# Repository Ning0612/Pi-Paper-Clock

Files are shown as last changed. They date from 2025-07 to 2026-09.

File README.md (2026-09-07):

# Pico Paper Clock







基於 Raspberry Pi Pico W 與 Waveshare 2.9 吋觸控電子紙的 IoT 時鐘。它定位成放在書桌前、低干擾常駐的小顯示器：讓人抬頭即可看到日期、時間、目前天氣、室內溫濕度與喜歡的圖片，也能透過環境光感測器估算並追蹤在書桌前的時間。裝置同時透過 Wi-Fi 提供設定、圖片管理與在席統計頁面。

> **與 [epaper-home-display](https://github.com/Ning0612/epaper-home-display) 的關係**：兩者是各自獨立維護的不同作品。本專案定位為簡易的桌前小時鐘，跑在 Pico W／MicroPython 的 264KB RAM 資源受限環境；epaper-home-display 則是以 Raspberry Pi Zero 2W／Python 打造、整合多種資訊來源的智慧家庭顯示面板。

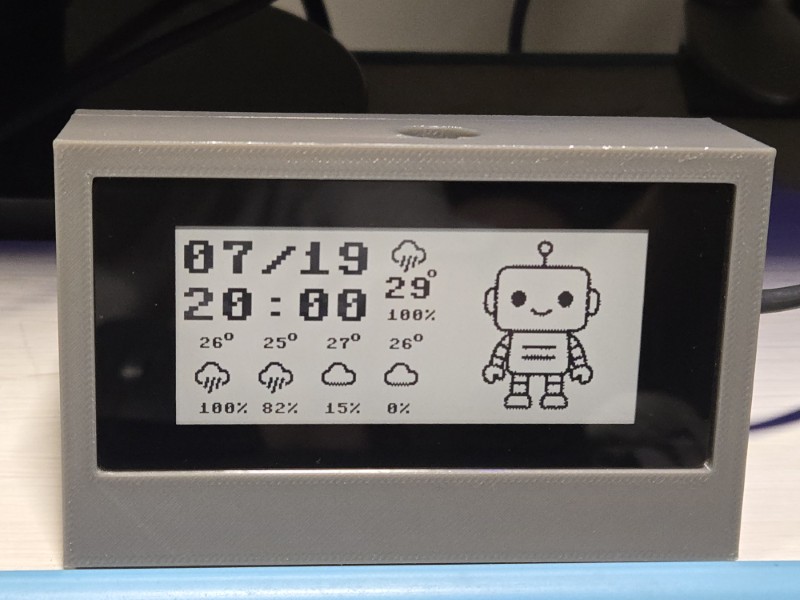
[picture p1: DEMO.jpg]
Project Demo


## Web UI 預覽

裝置在 AP 或 LAN 模式提供 Web UI，讓日常使用不必重新刷寫韌體即可管理顯示內容與查看書桌前活動：

- **裝置設定**：管理 Wi-Fi profile、天氣經緯度、圖片輪播、感測器與提示音，以及 AP 管理選項。
- **書桌前分析**：查看目前在席狀態、最近 24 小時與 30 天統計、年度熱力圖、每日紀錄和最近時段。
- **環境紀錄**：查看目前溫濕度、今日 min/max/avg，以及日/週/月/年趨勢圖與每日統計表。
- **圖片庫**：瀏覽 custom、events、login 圖片，預覽或刪除裝置上的素材；圖片上傳由 Pico Image Tool 處理。

<table>
  <tr>
    <td align="center">裝置設定頁<br><sub>裝置設定</sub></td>
    <td align="center">書桌前分析總覽<br><sub>書桌前分析：即時狀態與近期統計</sub></td>
  </tr>
  <tr>
    <td align="center">書桌前分析歷史資料<br><sub>書桌前分析：年度熱力圖與歷史紀錄</sub></td>
    <td align="center">圖片庫頁面<br><sub>圖片庫</sub></td>
  </tr>
</table>

## 功能概覽

- NTP 時間同步、目前天氣與未來預報。
- DHT22 溫濕度與環境光感測；低光時可讓電子紙進入休眠。
- 自訂圖片輪播、生日與 `MMDD` 事件圖片、觸控切換圖片。
- 多設定檔：依 Wi-Fi SSID 自動選擇家裡、公司等不同地點的設定。
- AP/LAN Web UI：管理設定檔、圖片、在席統計、環境紀錄與裝置狀態。
- 定時蜂鳴器提示，支援整點或每半小時響聲。

## 快速開始

### 1. 建立主機環境

Windows PowerShell：

```powershell
py -3 -m venv .venv
.\.venv\Scripts\python.exe -m pip install -r requirements.txt
```

完整部署流程、韌體安裝與疑難排解請參閱 [`docs/SETUP_GUIDE.md`](docs/SETUP_GUIDE.md)。

### 2. 準備設定並部署

1. 將 `src/config.json.example` 複製為未納入 Git 的 `src/config.json`，填入 Wi-Fi、各 profile 的天氣經緯度與其他設定；Open-Meteo 不需要 API Key。
2. 將 Pico W 以 USB 接上電腦，確認已安裝 MicroPython 與 `mpremote`。
3. 執行部署（將 `COM7` 換成實際序列埠）：

   ```powershell
   .\.venv\Scripts\python.exe tools\pico_deploy\upload_cli.py --port COM7 --no-config --no-clean
   ```

4. 啟動後若無法連上已知 Wi-Fi，裝置會建立 AP；連線至螢幕顯示的 SSID，再開啟 `http://192.168.4.1` 完成設定。

`tools\pico_deploy\upload_cli.py` 預設不會上傳或刪除裝置上的 `config.json`；只有明確指定 `--include-config` 才會納入本機設定。工具會在完成後重啟裝置並進入 REPL；按 `Ctrl+X` 離開。`--recursive-clean` 會刪除裝置上只存在於 runtime 的檔案與圖片，使用前請先備份。

`tools\pico_deploy\upload_cli.py` 是無 GUI 的 headless USB 部署入口；根目錄 `upload.py` 只保留作為相容 wrapper，一般 Windows 使用者可改用 Release 的 `PicoPaperClockTool` GUI。

## 硬體

必要元件為 Raspberry Pi Pico W、[Waveshare 2.9inch Touch e-Paper HAT](https://www.waveshare.net/wiki/Pico-CapTouch-ePaper-2.9)、LDR、DHT22、無源蜂鳴器與連接線。完整 pin map、接線圖與注意事項請見 [`docs/HARDWARE.md`](docs/HARDWARE.md)。

可選的 3D 外殼 CAD 檔案不放在 source tree；STEP 適合一般 CAD 編輯、STL 適合列印、SLDPRT 適合 SolidWorks 使用者，下載方式請見 [`docs/RELEASE_ASSETS.md`](docs/RELEASE_ASSETS.md)。

## 使用與設定

- 長按任一實體按鈕約 3 秒可要求裝置重啟並進入 AP 設定模式；不會刪除設定檔。
- AP 頁面可新增、編輯、刪除與切換設定檔；完整欄位、範圍、遷移與重置說明請見 [`docs/CONFIG_GUIDE.md`](docs/CONFIG_GUIDE.md)。
- 自訂圖片的資料夾、尺寸、事件命名與 GUI/CLI 用法請見 [`docs/IMAGE_GUIDE.md`](docs/IMAGE_GUIDE.md)。
- 圖片 HTTP API、認證要求與 `MONO_HLSB` 格式請見 [`docs/IMAGE_API.md`](docs/IMAGE_API.md)。
- Windows 使用者可下載 Release 的 `PicoPaperClockTool` EXE；序列部署時在 GUI 選擇含有 `src/` 的 repository/source zip，掃描序列埠後用選單選擇 Pico，部署前可在 Tree 檢視 manifest；LAN/AP 掃描結果也可選取，圖片批次上傳則可直接選取本機圖片。WebUI 帳號固定為 `admin`。

完全重置會刪除所有設定檔，必須在 AP 頁面的危險區域輸入 `RESET` 確認；這項操作無法復原。

## 開發與文件

```powershell
.\.venv\Scripts\python.exe tools\build_html.py
.\.venv\Scripts\python.exe -m unittest discover -s tests -v
```

GitHub Actions 會在 `main` push、pull request 與手動觸發時，以 Python 3.11/3.12 執行依賴安裝、HTML 生成物檢查、`compileall` 與 unittest。HTML 原始碼在 `tools/html_src/`，生成的 `src/html/*.bin` 不應手動編輯。專案資料流、記憶體限制與資料夾地圖請見 [`docs/ARCHITECTURE.md`](docs/ARCHITECTURE.md)，所有文件入口在 [`docs/README.md`](docs/README.md)。

桌面工具可由 source tree 建置：

```powershell
.\tools\build_pico_deploy_tool.ps1
```

輸出為 `dist\PicoPaperClockTool.exe`。建置與下載方式、序列部署安全選項及圖片批次流程請見 [`docs/IMAGE_GUIDE.md`](docs/IMAGE_GUIDE.md)。

## 授權與第三方資產

原創 source code 採用 [MIT License](LICENSE)。Waveshare 驅動與 weather-icons 圖示的授權邊界請見 [`THIRD_PARTY_NOTICES.md`](THIRD_PARTY_NOTICES.md) 與 [`ASSET_CREDITS.md`](ASSET_CREDITS.md)。

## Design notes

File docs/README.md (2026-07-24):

# Pico Paper Clock 文件索引

這個目錄收納需要長期維護的使用、設定、API 與架構文件；根目錄的 `README.md` 只保留專案介紹、快速開始與文件導覽，`AGENTS.md` 與 `CLAUDE.md` 保留給開發流程。

## 文件

- [架構與資料夾地圖](ARCHITECTURE.md) — 裝置資料流、記憶體邊界、圖片格式相容策略與維護規則。
- [硬體與接線](HARDWARE.md) — 元件、Pin map、感測器與蜂鳴器接線。
- [安裝、部署與 AP 設定](SETUP_GUIDE.md) — 主機環境、MicroPython、`tools/pico_deploy/upload_cli.py`、AP Web UI 與驗證。
- [設定指南](CONFIG_GUIDE.md) — schema v3、多設定檔、範圍與交易式保存。
- [圖片資產與轉換](IMAGE_GUIDE.md) — 資產目錄、尺寸、事件命名與 GUI/CLI。
- [圖片 API](IMAGE_API.md) — 裝置圖片列表、上傳、預覽、刪除與認證契約。
- [環境紀錄 API](ENV_LOG_API.md) — 溫濕度歷史記錄的取樣頻率、保留策略與 `/api/env/*` 契約。
- [Release assets](RELEASE_ASSETS.md) — GitHub Release 的 UF2、CAD 檔案與發布檢查表。

## 來源與生成物

- Web UI 原始碼位於 `tools/html_src/`。
- 執行 `tools/build_html.py` 生成 `src/html/*.bin`；不要直接編輯生成物。
- 圖片轉檔與 WebUI client 位於 `tools/pico_image_tool/`；Pico USB 部署核心與整合 GUI 位於 `tools/pico_deploy/`，入口為 `tools/pico_image_cli.py` 與 `tools/pico_image_gui.py`。

## 維護原則

1. API、設定欄位、硬體 pin 或資料夾變更時，更新對應詳細文件；根目錄 README 只維持摘要與入口連結。
2. 測試、PyInstaller 與 HTML 建置產物不放進 Git；`dist/` 僅作為本機交付物保留。
3. 既有使用者圖片、硬體 CAD 與網路上傳圖片不可因整理文件而刪除。

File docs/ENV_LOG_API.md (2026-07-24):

# Pico Paper Clock Environment Log API

環境（溫濕度）歷史記錄 API，架構與認證模型與 [`IMAGE_API.md`](IMAGE_API.md) 一致：只透過區域 HTTP 提供，皆為 **GET-only、唯讀**，只需 WebUI session cookie，不需要 CSRF token（因為不會異動任何狀態）。Server 不提供 CORS 或 TLS，只應暴露在可信任的 AP/LAN。

## 資料來源

DHT22 感測器每 `env_log.interval_min`（預設 15 分鐘，設定於 `global.env_log`，見 [`CONFIG_GUIDE.md`](CONFIG_GUIDE.md)）取樣一次，寫入 `env_events.log`（原始樣本）；每日 00:00 換日時彙總成一筆 `env_daily.log`（每日 min/max/avg），同時裁切掉 7 天前的原始樣本與 366 天前的每日彙總。裁切只在換日當下執行，不是即時保證——裝置斷電/關機一段時間後重開機，`env_events.log` 中舊資料要等到下一次換日才會被裁掉，這段期間查詢可能看到超過 7 天的資料。取樣獨立於在席狀態與畫面更新，離開書桌、螢幕休眠時仍會持續記錄。

## Collections

| Path | 方法 | 說明 |
|---|---|---|
| `/environment` | GET | 環境紀錄 WebUI 頁面（gzip 過的靜態頁面） |
| `/api/env/status` | GET | 目前溫濕度與今日 min/max/avg 統計 |
| `/api/env/samples` | GET | 原始樣本串流（保留視窗 7 天，於每日換日時裁切，非即時保證，見下方「資料來源」） |
| `/api/env/daily` | GET | 每日彙總串流（保留視窗 366 天，同上） |

## `/api/env/status`

```json
{
  "temp": 24.5, "hum": 55.2,
  "current_date": "20260721",
  "t_min": 22.1, "t_max": 26.8, "t_avg": 24.3,
  "h_min": 48.0, "h_max": 60.5, "h_avg": 54.1,
  "count": 18,
  "now_epoch": 1784712000
}
```

裝置尚未完成第一次取樣時，`temp`/`hum`/`t_min`/`t_max`/`t_avg`/`h_min`/`h_max`/`h_avg` 為 `null`、`count` 為 `0`。

## `/api/env/samples`、`/api/env/daily`

與 presence 的 `/api/desk/timeline`、`/api/desk/daily` 相同，使用 bounded streaming（逐行讀取＋512 bytes chunk 傳送），不會把整份 log 讀進記憶體。

`/api/env/samples` 回傳陣列，每筆為單一原始樣本：
```json
{"d":"20260721","tm":"1415","t":25.4,"h":58.0,"e":1784721300}
```

`/api/env/daily` 回傳陣列，每筆為單日彙總：
```json
{"d":"20260721","tmin":22.1,"tmax":29.8,"tavg":25.6,"hmin":45.0,"hmax":61.0,"havg":53.2,"n":96}
```

損壞或欄位不足的 log 行會被跳過，不會中斷串流。

## 錯誤與認證

未登入存取任何 `/api/env/*` 端點回傳 `401 {"error":"auth_required"}`；存取 `/environment` 頁面則導向 `/login`。裝置管理員密碼尚未設定時，所有端點皆視為需要先完成首次設定。

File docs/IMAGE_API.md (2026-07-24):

# Pico Paper Clock Image API v1

API 只透過區域 HTTP 提供。`GET /api/v1/device` 允許未驗證探索；裝置完成首次設定後，所有圖片清單與異動都需要 WebUI session cookie。`PUT`、`POST`、`DELETE` 另需 `X-Pico-Clock-API: 1` 與 session CSRF token。Server 不提供 CORS 或 TLS，只應暴露在可信任的 AP/LAN。

首次設定時，瀏覽器先以 `GET /api/v1/auth/status` 取得 per-boot CSRF token，再以 `POST /api/v1/auth/login` 設定固定帳號 `admin` 的管理密碼或登入。成功後回傳 `HttpOnly; SameSite=Strict` 的 `session` cookie 與 session CSRF token。裝置只保留一組 server-side session slot；新登入會使舊 session 失效，閒置 30 分鐘或絕對時間 24 小時後過期，重開機、登出或變更密碼也會失效。

## 探索

`GET /api/v1/device` 回傳固定的 `device: "pico-paper-clock"`、整數 `api_version: 1`、可用 heap/storage 與圖片尺寸。Client 必須拒絕未知 device 或 API 版本。

> v2.6.0 起裝置回傳的識別字串由 `pi-paper-clock` 改為 `pico-paper-clock`。桌面工具同時接受兩者，因此尚未更新韌體的裝置仍可正常連線。

## Collections

| Collection | Resource | 大小 |
|---|---|---:|
| custom | `/api/v1/images/custom/{name}.bin` | 解壓後 2,048 bytes |
| login | `/api/v1/images/login/{name}.bin` | 解壓後 4,736 bytes |
| events | `/api/v1/images/events/{MMDD|birthday}/{name}.bin` | 解壓後 2,048 bytes |

名稱由 1–48 個 ASCII 字母、數字、`_`、`-` 加上 `.bin` 組成。新工具上傳的 payload 一律是帶 PPC1 header 的 bitmap；PPC1 header 保存 bit order，裝置以 bounded streaming decoder 還原。API 仍接受既有固定長度 raw `MONO_HLSB`，並以 `.bin.hlsb` marker 維持舊資產相容性；無 marker 的既有 raw 圖片仍按舊版 MSB-left 讀取。

## 圖片操作

- `GET /api/v1/images?collection=custom|login|events&event=MMDD|birthday` 串流回傳 JSON `items`、`fs_free`、`catalog_generation`。
- `PUT <resource>?overwrite=0|1&preview=0|1` 需要 `application/octet-stream` 與精確 `Content-Length`。裝置會先串流寫入並驗證 raw／PPC1 解碼後長度，再以 `.part`、`.bak` 替換；開機會復原中斷交易。
- `DELETE <resource>` 刪除一張圖片並立即使 catalog 失效。
- `POST <resource>/preview` 排入一次電子紙預覽，不改變輪播順序。

上傳成功回應中的 `bytes` 是裝置實際儲存大小；`uncompressed_bytes` 是解壓後大小；`compressed` 表示是否使用 PPC1。

錯誤 body 為包含 `error` 與 `message` 的短 JSON；常見 status 為 `400`、`401`、`404`、`409`、`411`、`413`、`500`、`507`。

## 設定 Web API

- `GET /api/v1/config[?profile=name]` 回傳已遮蔽的 profile、profile 名稱、active profile、CSRF token 與「secret 已設定」布林值，永不回傳儲存的密碼、API key 或 webhook。
- `GET /api/v1/networks` 執行即時 Wi-Fi 掃描並回傳可見網路；掃描失敗回 `500`，不會修改既有設定。
- `POST /api/v1/config` 接受最多 4 KiB `application/x-www-form-urlencoded`，需要 CSRF token，驗證數字範圍，單次交易保存後排程重啟。空白 secret 欄位會保留原值。

所有受保護的 LAN/AP 設定 API 都需要 session cookie。設定異動、圖片異動與危險操作只接受 POST/PUT/DELETE，並驗證 `X-CSRF-Token`；圖片異動仍必須帶 `X-Pico-Clock-API: 1`。HTTP 沒有傳輸加密，session token 與 CSRF token 可能被同網段攻擊者攔截重放，請限制在可信任的隔離網路。

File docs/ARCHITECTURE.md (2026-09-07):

# 架構與資料夾地圖

## 裝置資料流

```text
main.py
  └─ AppController
       ├─ HardwareManager / PresenceManager
       ├─ ConfigManager（config.json，交易式 tmp/bak）
       ├─ ImageStore + ImageCatalog（串流列舉、輪播、預覽佇列）
       ├─ DisplayManager → RotatedCanvas90 → EPD_2in9
       └─ LanConfigServer / AP web server → wifi_manager dispatcher
```

啟動時先連線、同步 NTP 時間並嘗試發送 Discord LAN IP 通知；在載入控制器、顯示與感測器工作路徑前，會利用低記憶體窗口 flush pending Discord queue，再復原圖片交易檔並建立 LAN server。LAN 與 AP 共用路由；AP 額外保留按鈕長按、閒置 timeout、profile fallback 與 reboot 工作。

`main.py` 會在建立 controller 之前無條件畫出開機畫面，因此主迴圈接手時面板一定是醒著且有內容的。離席時的顯示收斂據此設計為**狀態驅動**：`state.display_asleep` 初值為 `False`，主迴圈只要看到 presence 不在席且旗標未設，就清屏、送入睡眠並設起旗標。之所以不能只監聽在席→離席的轉換，是因為在暗處開機時根本不存在該轉換（第一輪就已是離席），開機畫面會因此永遠留在面板上、電子紙也不會睡眠——而 Discord 記憶體保底重啟正好讓「暗處開機」成為常態路徑（見下方記憶體邊界）。圖片預覽也一併改為在迴圈開頭消耗、在在席分支繪製，**只取代該輪的頁面渲染而不短路整輪迴圈**；離席時預覽丟棄不繪製，面板維持睡眠。原本在迴圈開頭 `return` 的寫法讓客戶端只要每輪送一次 `preview=true`，就能使 `presence.update()`（連帶離席 debounce）、環境取樣、按鈕處理與 `_check_discord_stall()` 永遠不執行。

## 記憶體邊界

- 顯示使用一份 native `128 × 296` framebuffer，透過 rotated canvas 提供原本的 `296 × 128` 邏輯座標。
- 顯示更新會重用 native framebuffer、rotated canvas、字型 glyph buffer 與常用圖片列 buffer；避免每次刷新重新配置約 4.7 KB framebuffer 與重複的小型暫存物件。進入一般 Discord 網路傳送前會釋放大型 display workspace，保留 TLS 所需的連續 heap 空間。
- 圖片以固定列 buffer 讀取；網路上傳以 512-byte buffer 串流，不把整張圖片載入 RAM。
- SPI 傳送使用 buffer write，避免逐 byte 建立暫時物件。
- 長生命週期 controller、presence、image store/catalog 使用 `__slots__`。
- Discord webhook 不使用 `urequests.Response` 路徑，改用 raw `ssl` socket：只建立固定大小的 HTTP headers/payload、處理 partial write、讀取 status line 後立即關閉 socket；送出前後執行 `gc.collect()`，並暫時調整 GC threshold 後恢復原值。NTP 會在第一次 TLS 呼叫前同步；目前 firmware tree 尚未附帶 CA trust anchor，因此此連線仍不能宣稱完成憑證鏈／hostname 驗證，正式部署前需補上 CA bundle，不能以不驗證的 TLS 取代。
- Discord JSON payload 以單一 `bytearray` 組裝，避免字串串接時留下額外完整 payload copy；Discord socket 在建立與 TLS 前會記錄 heap free/allocated telemetry。
- 啟動通知與 pending Discord queue 在 `main.py` 的低依賴啟動階段先執行，避開 controller/weather 後續模組 import 與 display/hardware 工作物件建立造成的 heap 碎片；第一次失敗不阻塞主程式，controller 會在 45 秒後、每 30 秒重試，pending queue 則保留到下一次可用窗口（`presence_pending.log`／`presence_session_pending.log` 另有 7 天保留上限，超過天數的通知會被裁切捨棄，不會無限期等待重試，見下方「Flash 儲存邊界」）。
- **記憶體自動重啟後，IP 未變就不再送「已上線」通知**。那次重啟買到的是唯一一個可用的 TLS 窗口，而啟動階段原本第一件事就是重發一則使用者早已知道的 IP 通知，把窗口用掉、pending 在席通知只能再等下一次重啟（至少 2 小時）。`_check_discord_stall()` 因此在 `machine.reset()` 前把當下**已公告過**的 IP 寫入 `discord_autoreset_ip.log`，`main.py` 在啟動窗口讀取後立即刪除：IP 相同就跳過通知並標記為已送（避免 controller 每 30 秒重試），窗口留給 `flush_startup_discord()`。只記錄確實送出過的 IP——從未公告成功的位址仍要照常嘗試，否則使用者無從得知裝置在哪。記錄採**讀取即消費**，所以手動斷電重開、或 IP 真的變了，都會照常送出；消費在「是否連上網路」的判斷之外執行，否則一次沒連上線的開機會把記錄留給後面某次本該公告的開機。刪除失敗時視為「沒有消費到任何東西」並照常公告——殘留的記錄否則會在每一次相同 IP 的開機持續抑制通知，多送一則遠優於從此靜默。「IP 沒變」的定義就是 IPv4 字串相同：換到另一個網路卻拿到相同位址時同樣會被抑制，但公告過的 URL 在該網路上仍然可用，且記錄只存活於「自動重啟 → 它造成的那次開機」之間，搬移裝置必然經過斷電而清掉記錄。
- Discord `ENOMEM` 會回傳可重試結果；presence queue 在記憶體壓力後暫停一個 flush interval，之後自動恢復嘗試，不丟棄 pending session/summary。
- **TLS 需要的是連續區塊，不是可用總量**。`ssl.wrap_socket` 的成敗門檻量測（MicroPython 1.24.1，2026-07-25，純 `.py` 部署）：最大連續區塊 17,920 B 時直接 `OSError [Errno 12] ENOMEM`，23,120 B 時成功。`TLS_MIN_CONTIGUOUS_BYTES` = 20 KiB 即取自這段區間。實測清除天氣快取與重複 `gc.collect()` 對最大連續區塊完全無效。
- **目前的 heap 基線見下方 2026-07-26 複測，不是上一行的 17.9 KB**。上一行只用於界定 TLS 的成敗門檻；當時記錄的「運行中最大連續區塊約 17.9 KB」已被後續量測取代，勿再引為現況基線。
- **`release_display_workspace()` 增加的是 `mem_free`，不是最大連續區塊**。2026-07-26 於 `.mpy` 部署、開機約 3 分鐘的實機複測：呼叫後 `mem_free` 由 56,512 B 升至 61,584 B（+5,072 B），但最大連續區塊在呼叫前後**同為 10,240 B，完全沒有移動**——釋放出的空間不在關鍵位置。同次量測的穩態為 `mem_free` 56,512 B／`mem_alloc` 133,440 B，最大連續區塊約 10 KiB，**只有 20 KiB 門檻的一半**；裝置端 `discord_diag.log` 同期記錄的 `largest=10240`／`13312` 與此一致。因此在這個部署下，穩態送不出去是常態而非暫時性壓力，而**目前唯一觀察到能成功送出的時機**是重開機後、模組尚未載入的低記憶體啟動窗口（`main.py` 的 `flush_startup_discord()`）。此結論的證據是單一裝置、單一韌體與 `.mpy` 部署下的量測，其他部署模式（純 `.py`、不同韌體、模組數量變動）需重新量測才能沿用。不要再把 `release_display_workspace()` 當成能救回這條路徑的手段。
- `flush_discord()` 因此在釋放 display workspace 之後、送信之前執行 pre-flight 檢查（`has_tls_headroom()`，門檻 `TLS_MIN_CONTIGUOUS_BYTES` = 20 KiB）。不足時跳過本次嘗試並累計失敗計數，避免把約 3 秒耗在必定失敗的 handshake 上。失敗原因與當下最大連續區塊寫入 `discord_diag.log`（第 1 次與其後每 10 次），失敗診斷因此能在斷電後保留。
- **記憶體探針之前必須先問「這則訊息本來就送得出去嗎」**：`delivery_blocked()` 會先判斷 webhook 是否設定、STA 是否連線，回傳 `nowebhook`／`offline`／`""`。順序反過來的話，「沒設定 webhook」或「斷網」會被記成記憶體不足，累積後觸發一個根本幫不上忙的重開機。三個 `send_*` 函式共用同一份判斷，避免兩處條件漂移。
- 碎片化一旦讓連續區塊長期不足，**只有重開機能取回連續 heap**。`app_controller` 在**記憶體類失敗**（`lowmem`／`enomem`，由 `presence.discord_mem_failures` 單獨計數）達門檻、仍有 pending、且開機滿 `DISCORD_STALL_MIN_UPTIME_MS`（5 分鐘）時執行 `machine.reset()`。HTTP 錯誤或斷網會把該計數歸零，**因此這類失敗本身不會觸發任何重啟**——這正是歸零的目的：重開機修不好一個被刪除的 webhook，少了這道區分才會退化成每 2 小時重啟一次。
- **門檻依在席狀態而定，因為它衡量的是重開機當下的代價，不是堵塞已持續多久**（`_stall_reset_threshold()`）。離席時 `DISCORD_STALL_AWAY_FAILURES`（2 次，約 2 分鐘）：`presence_manager` 只在「離開書桌」的 transition 產生 pending session summary，所以幾乎所有待送通知誕生時面板都已清屏睡眠、使用者不在場，重開幾乎沒有可感知的代價。在席或狀態未知（`current_state` 為 `None`，第一次 presence 判定之前）時 `DISCORD_STALL_PRESENT_FAILURES`（10 次，約 10 分鐘），因為重開會讓使用者盯著開機畫面等 Wi-Fi 重連與 NTP。**在席門檻不可改成「永不」**：光感若把亮著的空房間讀成在席，only-away 觸發就永遠不會發生，通知會卡得比引入這個機制之前更久。
- 觸發判斷採 `stall_checked_failures`／`stall_checked_threshold` latch，不是「失敗數為門檻的整數倍」。同一組（失敗數，門檻）只評估一次，因此冷卻檔仍維持每次失敗才讀一次（約 60 秒），不會每輪主迴圈都讀 flash；而失敗數或門檻任一改變就重新評估，所以使用者離開書桌使門檻下降時會立即重評，被 uptime gate 或冷卻擋掉的檢查也只延後到下一次失敗（約 60 秒），不像倍數寫法會直接延到第 2N 次而使延遲加倍。這也解除了 gate 與門檻的耦合：`DISCORD_STALL_MIN_UPTIME_MS` 只需長於啟動通知窗口（`STARTUP_DISCORD_DELAY_MS` 加一次 `STARTUP_DISCORD_RETRY_MS`），由 `test_uptime_gate_outlasts_the_startup_window` 把關。失敗數在送出成功後歸零時 latch 一併重設，避免計數重新爬回同一個值時漏掉一次評估。
- 門檻降低**不保證**「每批 backlog 只花一次重啟」：pending 是以 `_append_line` 累積、`_drop_first_line` 消耗的佇列，而 `flush_startup_discord()` 每次開機最多清 8 筆，冷卻是 per-reboot 而非 per-backlog。目前每天約 2–6 筆的量遠低於此上限，但 backlog 一旦深於 8 筆，清空就需要跨多次重開機。
- 自動重啟的保險：pending 未能寫入 flash（`pending_persist_failed`）時放棄重啟，否則會遺失只存在於 RAM 的通知；冷卻時間戳寫入失敗時放棄重啟並封鎖本次開機（fail-safe，不重啟優於 boot loop）；`discord_autoreset.log` 於執行期即時評估，冷卻可在運行中自然到期。**冷卻檔只有「檔案不存在」是 fail-open，其餘一律 fail-closed**：不存在代表從未自動重啟過，第一次不可被擋；其他讀取錯誤（`OSError` 非 ENOENT）與時鐘不可用則直接拒絕，因為此時冷卻狀態是「未知」，而未知不能讀成「允許」——間歇性的 flash 讀取失敗否則每失敗一次就放行一次重啟。檔案存在但內容不可用（截斷寫入、區塊損毀、`<= 0` 的數值）則重寫一個新的時間戳並拒絕本次重啟；若連重寫都失敗就設起 `auto_reset_blocked`，與呼叫端寫入失敗時的處置一致。**時間戳比當下時鐘還新時同樣走重寫路徑**：Pico W 沒有電池供電的 RTC，NTP 同步失敗的那次開機會讓 `time.time()` 從 port epoch 重新起算，於是由已同步開機寫下的時間戳永遠落在未來、差值恆為負；把它讀成「冷卻未到期」會讓保底重啟一路被封鎖到 NTP 再次成功，讀成「已到期」則會每輪都放行、而每次重啟又重置時基。重寫成當下時基並等滿一次冷卻是唯一不會卡死也不會失控的處置。把損毀讀成「從未重啟過」等於放棄唯一的 boot-loop 防護，而在離席門檻（約 2 分鐘）下那會退化成每次 uptime gate 到期就重開一次。
- **離席分支的清屏睡眠必須包在 try/except 內**：`main.py` 以 `while True: controller.run_main_loop()` 裸迴圈驅動、未包例外處理，而 `clear_display_and_sleep()` 位於 `_check_discord_stall()` 之前，因此它拋出的例外會終止整個主程式，並讓最需要保底重啟的時刻永遠等不到重啟。失敗時不設起 `display_asleep`，但改以 `DISPLAY_SLEEP_RETRY_MS`（60 秒）退避後再試——完整清屏加面板初始化的成本太高，每秒重試一次會排擠 LAN polling、presence 更新與 stall 檢查並灌爆 UART log。「開機滿 5 分鐘」以 latch 記錄而非每次重算——`ticks_ms()` 為 30-bit、`ticks_diff()` 僅在約 ±6.2 天內有效，而這個故障正好出現在約 12 天的連續運行之後。
- DHT22 使用 2500 ms 最小讀取間隔；讀取失敗改用 10 秒 backoff，保留上一筆快取值，避免感測器錯誤反覆消耗 heap 與刷 serial log。
- 天氣資料改由 Open-Meteo 提供：current request 取得目前溫度與 WMO condition code，daily request 取得 5 天平均/高低溫、降雨機率與降水量；以 `response.json()` 解析小型 5-day payload，完成後立即釋放 response 與資料物件並回收 heap。既有 display icon 名稱由 WMO code mapping 保持不變。
- 天氣 request 前、response 取得後與 forecast parse 後會記錄 heap telemetry；API 的 `timezone` 由 profile 的固定 `timezone_offset` 轉成 IANA `Etc/GMT` zone，使預報日期與裝置日期一致。Presence API 的記憶體讀取介面只保留最近 128 筆事件與 366 筆 daily lines，且單行最多讀取 256 字元；完整串流 API 仍逐行送出。
- `/api/v1/device` 的 `heap_free` 可作為現場基線；完整 peak／長跑數據仍需接上指定 Pico 後量測。

### 記憶體問題的處理原則

```text
啟動 Wi-Fi
  └─ raw HTTPS Discord webhook
       ├─ 成功：記錄已送出，釋放 socket
       └─ ENOMEM：保留可重試狀態，不阻塞主迴圈
            ↓
載入 display / HardwareManager / AppController
  └─ 天氣 forecast 以 5-day JSON payload 解析並立即釋放
  └─ DHT22 依時間節流，失敗使用 backoff 與快取
```

這些策略的目標是降低「單次配置峰值」與重複配置頻率，而不是宣稱裝置 heap 永遠不會耗盡。現場診斷應同時查看 serial 的 `ENOMEM`、`Memory before/after ...` telemetry、DHT22 錯誤與 `/api/v1/device` 的 `heap_free`。**Discord 送不出去時優先查裝置上的 `discord_diag.log`**：`lowmem` 事件附帶當下的最大連續區塊，可直接判斷是碎片化還是 webhook 本身的問題（後者記錄為 `http<狀態碼>`）。注意 `heap_free` 充足並不代表 TLS 可用——關鍵指標是最大連續區塊。

## Flash 儲存邊界

`presence_manager.py` 與 `env_manager.py` 的 log 檔案都存在裝置的內部 flash 檔案系統上，與韌體、`config.json`、`src/image/` 圖片資產共用同一個有限空間（在一台已使用一段時間、圖片庫已有內容的裝置上，剩餘可用空間可能只有約 100 KiB 等級）：

- 兩個模組都採「事件/樣本檔＋每日彙總檔」的雙檔設計，並在每日換日時以 `_trim_by_date` 依日期視窗裁切——檔案大小會在保留視窗內收斂到穩定值，不會隨時間無限增長。
- `env_events.log`（15 分鐘取樣、7 天保留）穩態約 17 KiB；`env_daily.log`（每日彙總、366 天保留）穩態約 15 KiB；新增的 `environment.bin` WebUI 資產約 6.7 KiB（實測，`tools/build_html.py` 輸出）。三者合計約 40 KiB 是這次新增功能的穩態 flash 佔用。
- 裁切/換日時的 `.tmp`/`.bak` 交易寫入（`_commit_tmp`）會暫時需要被重寫檔案的一整份額外空間；`env_events.log` 裁切瞬間約需額外 17 KiB。
- `discord_diag.log` 上限 6 KiB，超過時串流捨棄較舊的一半（同樣使用 `.tmp` 交易寫入，瞬間額外需求不超過檔案本身）；`discord_autoreset.log` 只存一個 epoch 時間戳，`discord_autoreset_ip.log` 只存一個 IP 字串且讀取後即刪除，量級皆可忽略。
- **實測建議**：完成部署後應以裝置 REPL 執行 `os.statvfs('/')` 或呼叫 `GET /api/v1/device` 的 `fs_free` 欄位覆核實際剩餘空間，不要只依賴這裡的估算值。7 天保留的原始/事件 log（`env_events.log`、`presence_events.log`）約一個月內就會穩定在保留視窗內的穩態大小；366 天保留的每日彙總 log（`env_daily.log`、`presence_daily.log`）要接近一整年才會長到穩態上限，短期量測看到的每日彙總檔案會比長期穩態小很多，不能用一個月的量測值直接外推。若空間明顯吃緊，`env_manager.DAILY_RETENTION_DAYS`（預設 366，比照 `presence_manager.DAILY_RETENTION_DAYS`）可調降以換取空間。
- **`.py` 原始碼是目前最大宗的 flash 佔用來源**：一台已部署 presence／env 功能且圖片庫有內容的裝置，18 個 `.py` 檔案合計約 226 KB，佔裝置總佔用（307 KB）的 74%，遠超過圖片資產（~50KB）與 Web UI `.bin` 資產（~38KB）。`tools/pico_deploy/upload_cli.py --mpy` 可在部署前用 `mpy-cross` 把 `.py` 預編譯成 `.mpy` bytecode（`epaper.py`／`main.py`／`config.json` 除外，理由見 `CLAUDE.md`「部署至裝置」一節），是目前最有效的省空間手段。**實測**（2026-07-22，裝置 MicroPython 1.24.1）：18 個原始碼檔案從約 226 KB 壓到約 101 KB，裝置剩餘 flash 從 88.0 KiB 提升到 204.0 KiB（多出 116 KiB），比社群估計的 30–50% bytecode 縮減比例更好。**裝置剩餘空間吃緊時建議部署加上 `--mpy`**；這仍是 opt-in 選項而非預設行為——目前沒有部署前韌體版本檢查機制，`mpy-cross` 版號與裝置實際韌體版本漂移會讓 `.mpy` 模組 import 失敗，加上回滾（切回純 `.py`）流程尚未完整驗證，暫不建議設為預設。

## 圖片格式與相容性

- raw 圖片 payload 的 canonical 格式是 `MONO_HLSB`，每個 byte 的 bit 0 是最左像素；新工具一律寫入帶 HLSB header 的 PPC1 `.bin`。
- PPC1 header 保存 bit order，裝置透過 256-byte history、512-byte input buffer 與既有 row buffer 逐列解壓，不把整張圖片載入 RAM。
- 新工具與 USB manifest 不建立或部署 `.hlsb` sidecar；PPC1 自帶 bit order metadata。
- 韌體仍接受 raw API／既有 raw 資產的 `.hlsb` marker，以維持升級相容性。
- 沒有 marker 的既有 repository／舊版 runtime raw `.bin` 仍按 MSB-left 解碼，避免升級時破壞既有圖片。
- `custom`／`events` 為 `128 × 128`、2048 bytes；`login` 為 `296 × 128`、4736 bytes。

## HTTP 邊界

- `/api/v1/device` 可匿名讀取；圖片與設定 API 在完成首次設定後需要 WebUI server-side 單一 session、CSRF token，圖片變更另需 `X-Pico-Clock-API: 1`。
- 設定頁、圖片頁、儀表板與感測資料在 LAN/AP 共用同一 session dispatcher；首次出廠 AP 允許完成首次密碼設定，之後即要求 session。
- session 使用 128-bit CSPRNG token、idle 30 分鐘／absolute 24 小時 monotonic timeout；重開機、登出與密碼變更會撤銷 session。管理密碼以 PBKDF2-HMAC-SHA256 儲存。
- 管理介面仍是 HTTP；請限制在可信任的隔離 LAN/AP，因 HTTP 無法防止 session token 被同網段攔截重放。
- body 只接受單一 `Content-Length`，拒絕重複長度與 `Transfer-Encoding`。
- request 有總讀取 deadline；Pico W 正常圖片串流使用 8 秒上限。
- 圖片寫入採 `.part`、`.bak` 與 marker transaction，開機會復原未完成狀態。

## 資料夾地圖

| 路徑 | 用途 | 維護規則 |
|---|---|---|
| `src/` | MicroPython firmware | 不使用 CPython-only API |
| `src/image/` | 裝置圖片資產 | 保留既有圖片；API runtime 圖片由裝置管理 |
| `src/html/` | 生成後的 Web UI `.bin` | 由 `tools/html_src/` 建置 |
| `tools/html_src/` | 可讀 HTML/CSS/JS 來源 | UI 修改只改這裡 |
| `tools/pico_image_tool/` | 圖片轉檔、抖動、codec、WebUI client、圖片 CLI | 主機端 Python |
| `tools/pico_deploy/` | Pico USB/`mpremote` 部署核心、manifest、作業佇列與整合 GUI | 主機端 Python |
| `tests/` | 主機回歸與協議測試 | 使用專案 `.venv` |
| `docs/` | 長期文件與契約 | API／設定／架構同步更新 |
| `dist/release-assets/` | 本地發布暫存的 UF2、STEP、STL 與 `.SLDPRT` | 已被 Git 忽略；建立 Release 時手動附加；不放回 source tree |

## 部署與驗證

```powershell
.\.venv\Scripts\python.exe tools\build_html.py
.\.venv\Scripts\python.exe -m unittest discover -s tests -v
.\.venv\Scripts\python.exe tools\pico_deploy\upload_cli.py --port COM6 --no-clean
```

本次記憶體路徑的最低驗證包括 host tests、`compileall`、`git diff --check`，以及 Pico W serial 中的 `Success: Discord LAN IP notification sent.`、DHT22 讀值與天氣請求成功。完整 peak heap 仍應以實際硬體長跑資料為準。

Pico 部署工具 EXE 由 `tools/build_pico_deploy_tool.ps1` 建置。若使用遞迴清理，部署前要先保存裝置上只有 runtime 的圖片。

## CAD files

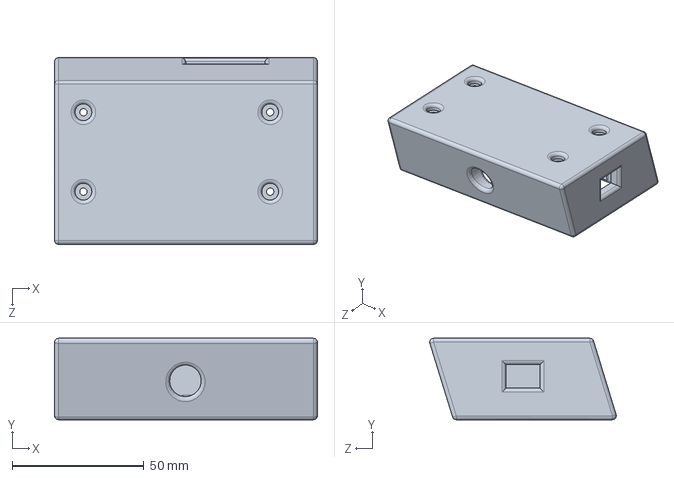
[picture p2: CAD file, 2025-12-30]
hardware/clock_v3.SLDPRT
100.0 x 31.0 x 71.0 mm

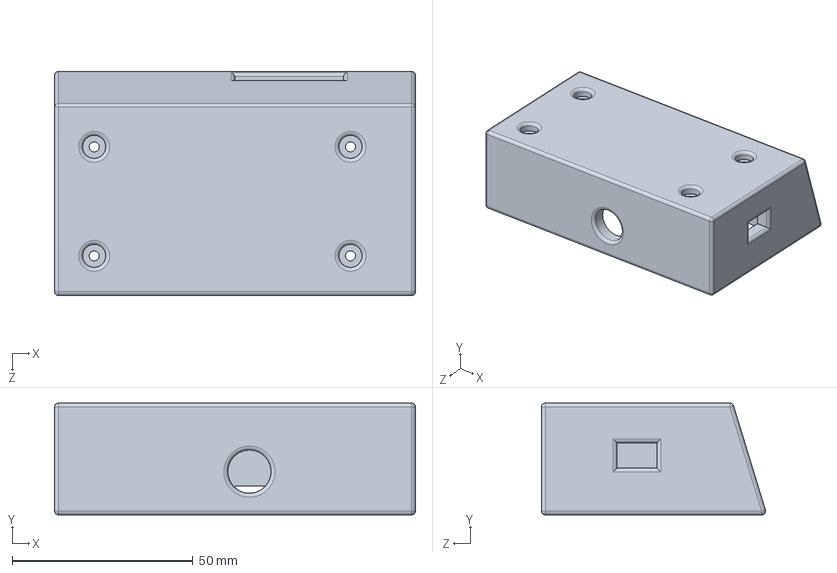
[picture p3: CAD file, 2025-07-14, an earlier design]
hardware/clock.SLDPRT
100.0 x 31.0 x 62.1 mm

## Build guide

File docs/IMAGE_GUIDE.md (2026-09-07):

# 圖片資產與轉換

本文件說明 repository 內的圖片資產、整合式桌面上傳工具與批次流程；HTTP 上傳、認證、交易寫入與位元排列請以 [`IMAGE_API.md`](IMAGE_API.md) 為準。

## 資產目錄

所有裝置圖片位於 `src/image/`，以 1-bit bitmap 儲存。新工具一律輸出帶 PPC1 header 的 `.bin`；即使壓縮後稍大，也不會產生 `.bin.hlsb` sidecar：

| 路徑 | 用途 | 尺寸 |
|---|---|---:|
| `custom/` | 一般輪播圖片 | 128 × 128 |
| `events/birthday/` | 生日圖片 | 128 × 128 |
| `events/MMDD/` | 特定日期圖片，例如 `events/1225/` | 128 × 128 |
| `login/` | 啟動與連線過渡畫面 | 296 × 128 |
| `weather_icons/` | 天氣狀態圖示（依 WMO code 對應） | 32 × 32 |

事件資料夾使用四位數 `MMDD`；檔名使用 `.bin`。Weather icons 是系統資產，不透過圖片 API 修改。

## 整合 GUI 與 CLI

GUI 入口：

```powershell
.\.venv\Scripts\python.exe tools\pico_image_cli.py gui
```

GUI 由 `tools/pico_deploy/` 提供，分成序列部署、圖片批次與作業佇列；圖片轉檔與 WebUI client 仍由 `tools/pico_image_tool/` 提供。序列部署前請在「工作階段連線」選擇含有 `src/` 的專案目錄，按「掃描序列埠」後從下拉選單選擇 Pico；Release 的 Windows EXE 不會把客製設定與資源硬編進工具，因此也必須選擇 repository 或 GitHub source zip 解壓後的目錄。

WebUI 登入帳號固定為 `admin`，GUI 只要求輸入暫存於本次工作階段的管理密碼。按「掃描 LAN」會先探測目前欄位中的位址，再查 Windows ARP 快取，最後補掃本機 IPv4 `/24` 網段與預設 AP 位址；即使 Pico 尚未出現在 ARP 快取，也能透過網段掃描找到。掃描結果會放入 LAN/AP 位址選單，也可以手動輸入 IP。序列部署的預設行為是保守模式：預設不清理裝置、不覆寫 `config.json`，並在加入佇列前以 Tree 顯示本機路徑、遠端路徑、分類、檔案大小與總大小。遞迴清理會刪除裝置上未保存在本機的檔案，只有在明確勾選 config 並確認警告後才能使用。

圖片批次清單的每一項可獨立設定 collection、event、檔名、fit、dither、threshold、反相、覆寫與上傳後預覽。圖片會先在本機旁保存 PPC1 `.bin`，再以已登入的 WebUI session 上傳。

「完整同步」是額外的作業 macro：先完成 USB 資源部署並重啟，接著以 LAN/AP 位址輪詢裝置最多 60 秒，恢復連線後才執行圖片佇列；網路恢復失敗時會停止並保留未執行圖片。

Windows EXE 建置：

```powershell
.\tools\build_pico_deploy_tool.ps1
```

輸出 `dist\PicoPaperClockTool.exe`。也可直接使用 Python/CLI，不需要 PyInstaller。

CLI 範例：

```powershell
.\.venv\Scripts\python.exe tools\pico_image_cli.py discover
.\.venv\Scripts\python.exe tools\pico_image_cli.py convert photo.png --type custom
.\.venv\Scripts\python.exe tools\pico_image_cli.py upload photo.png --device 192.168.1.50 --type custom --preview
.\.venv\Scripts\python.exe tools\pico_image_cli.py upload holiday.png --device 192.168.1.50 --type events --event 1225
```

工具支援 Floyd–Steinberg、Atkinson、Bayer 4x4、固定 threshold，以及 `cover`、`contain`、`stretch` 縮放策略；透明圖會先合成白底並套用 EXIF 方向。GUI/CLI 預設在原圖旁保留 PPC1 `.bin`，方便在裝置清理後重新部署。

## 格式與部署注意事項

raw payload 的 canonical `MONO_HLSB` 是每個 packed byte 的 bit 0 代表最左側像素。PPC1 header 會自行保存 bit order，裝置以 256-byte history、512-byte input buffer 與 row buffer 逐列解壓，不會配置整張圖片。

- 新工具產生的 `.bin` 一律是 PPC1，header 會保存 HLSB bit order，不需要 sidecar；`tools/pico_deploy/upload_cli.py` 只部署 `.bin`。
- 韌體仍可讀取既有 raw `.bin` 與 `.bin.hlsb` 相容資產；這些舊資產需轉換成 PPC1 後才能符合「只有 `.bin`」的檔案規則。

圖片 API 目前支援 custom、login、events 三個 collection，尺寸與 byte length 請見 [`IMAGE_API.md`](IMAGE_API.md)。

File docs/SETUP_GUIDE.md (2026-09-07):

# 安裝、部署與 AP 設定

本文件描述從主機環境到 Pico W 的完整使用流程。`README.md` 只保留快速開始；設定欄位本身以 [`CONFIG_GUIDE.md`](CONFIG_GUIDE.md) 為準。

## 主機環境

專案主機工具使用 Python 3.11+ 與專案 `.venv`。PowerShell 執行：

```powershell
py -3 -m venv .venv
.\.venv\Scripts\python.exe -m pip install -r requirements.txt
```

執行主機測試或工具時都使用 `.venv` 裡的 Python，不要改用全域 Python。

## 安裝 MicroPython

1. 從 [MicroPython Pico W 下載頁](https://micropython.org/download/RPI_PICO_W/) 下載 `.uf2`；已驗證的版本也可能放在 [GitHub Releases](https://github.com/Ning0612/pico-paper-clock/releases)。
2. 按住 Pico W 的 `BOOTSEL`，再以 USB 接上電腦。
3. 將 Pico 顯示的 `RPI-RP2` 磁碟機開啟，把 `.uf2` 拖入其中。
4. 等待裝置自動重啟。

## 準備設定

`src/config.json` 可能含有 Wi-Fi 密碼與 API secret，已被 `.gitignore` 忽略。第一次使用時建立本地設定檔：

```powershell
if (!(Test-Path src\config.json)) { Copy-Item src\config.json.example src\config.json }
```

再編輯 `src/config.json`，至少填入一個 profile 的 Wi-Fi 設定與天氣經緯度；Open-Meteo 不需要 API Key。完整 schema、數值範圍與 secret 欄位請見 [`CONFIG_GUIDE.md`](CONFIG_GUIDE.md)。

## 上傳韌體檔案

`tools/pico_deploy/upload_cli.py` 需要 `mpremote`，會上傳 `src/` 中的 Python、圖片與 WebUI，預設保留裝置上的 `config.json`，完成後重啟裝置並開啟互動式 REPL；根目錄 `upload.py` 仍可作為相容 wrapper：

```powershell
.\.venv\Scripts\python.exe tools\pico_deploy\upload_cli.py --port COM7 --no-clean
```

常用參數：

| 參數 | 用途 |
|---|---|
| `--port COM7` | 指定 Pico W 序列埠；未指定時由 `mpremote` 自動偵測 |
| `--no-images` | 不上傳圖片 |
| `--no-config` | 不上傳也不刪除裝置上的 `config.json` |
| `--include-config` | 明確允許上傳本機 `config.json`；會覆寫裝置設定，僅在確認目的地時使用 |
| `--no-clean` | 跳過部署前清理 |
| `--recursive-clean` | 遞迴刪除裝置檔案與目錄後再部署 |
| `--mpy` | 部署前用 `mpy-cross` 將 `.py` 預編譯為 `.mpy` 省 flash（`epaper.py`／`main.py`／`config.json` 除外），opt-in、非預設行為，需額外 `pip install mpy-cross==1.24.1.post3`（僅部署時需要，裝置本身不需要）；實測可省下裝置約 100 KiB 以上的剩餘空間，細節見 `docs/ARCHITECTURE.md`「Flash 儲存邊界」 |

`--recursive-clean` 會刪除只存在裝置上的網路上傳圖片，除非已完成備份，否則不要使用。REPL 中按 `Ctrl+X` 離開。

**裝置剩餘 flash 空間不足時，建議部署加上 `--mpy`**（例如 `.\.venv\Scripts\python.exe tools\pico_deploy\upload_cli.py --port COM7 --mpy`），可以省下相當可觀的空間；不需要省空間、或想直接在裝置上讀原始碼除錯時，用標準部署（不加 `--mpy`）即可。目前 `mpy-cross` 版號是釘死對應特定韌體版本，尚未成為預設行為。

## 整合式桌面上傳工具

Windows 使用者可從 GitHub Release 下載 `PicoPaperClockTool` EXE；從 source tree 建置則執行：

```powershell
.\tools\build_pico_deploy_tool.ps1
```

在 GUI 的「工作階段連線」中選擇含有 `src/` 的 repository 或 source zip 解壓目錄，按「掃描序列埠」後從選單選擇 Pico；LAN/AP 則可掃描後選取或手動輸入。WebUI 帳號固定為 `admin`，只需輸入管理密碼。GUI 會提供：

- 序列部署前以 Tree 預覽 manifest（本機／遠端路徑、分類與大小）、Python/JSON、WebUI、圖片與 config 選項，以及「預編譯 .mpy（省 flash，epaper.py／main.py 除外）」勾選框，效果同 CLI 的 `--mpy` opt-in 選項。
- LAN/AP 圖片批次轉檔、預覽、認證上傳與每張圖片獨立設定。
- 由序列部署與圖片上傳組成的完整同步作業。

GUI 預設不清理裝置，也不覆寫 `config.json`。遞迴清理與 config 覆寫會要求額外確認；密碼只保留在目前工作階段，不會寫入磁碟。

## AP 模式設定

裝置在找不到任何已知 Wi-Fi 時會自動進入 AP 模式。正常運作時長按任一 HAT 按鈕約 3 秒，也會要求重啟並進入 AP 模式；這不會刪除 profile。

1. 查看電子紙顯示的 AP SSID、密碼與 IP。預設 IP 是 `192.168.4.1`，預設 SSID/密碼是 `Pi_Clock_AP` / `12345678`。
2. 用手機或電腦連線到該 AP。
3. 開啟 `http://192.168.4.1`。
4. 在設定頁選取或建立 profile，填入 Wi-Fi SSID、密碼、天氣緯度／經度、時區、光感門檻與響聲設定。
5. 按下儲存並重啟；裝置會將該 profile 設為 active profile。

AP 頁面也提供圖片庫、在席統計與完全重置入口。LAN 模式的設定與圖片管理受認證保護；不要把裝置服務暴露在不可信任的網路。

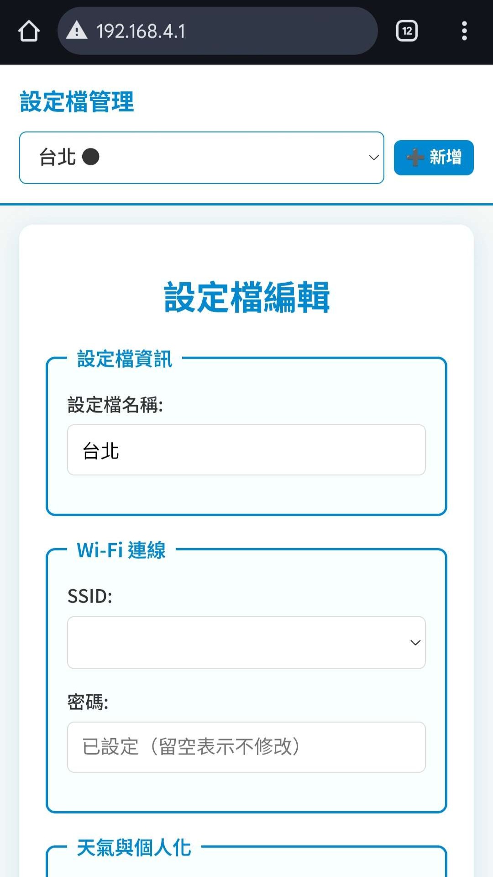
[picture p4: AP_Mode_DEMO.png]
AP Mode Web UI


## Web UI 建置

修改 AP 頁面時，只編輯 `tools/html_src/`，再生成裝置使用的 gzip `.bin`：

```powershell
.\.venv\Scripts\python.exe tools\build_html.py
```

不要直接編輯 `src/html/*.bin`。裝置 Web server 會回傳 `Content-Encoding: gzip`；完整 Web UI 工作流程另見專案的 `build-web-ui` skill。

## 驗證

```powershell
.\.venv\Scripts\python.exe -m compileall tools tests upload.py
.\.venv\Scripts\python.exe -m unittest discover -s tests -v
```

部署後應在 Pico W 上確認能顯示時間、連線天氣、讀取 DHT22/LDR，並可從 AP 或 LAN 頁面完成設定。

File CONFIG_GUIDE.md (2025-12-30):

# Pi-Paper-Clock 設定檔說明

## 📋 多設定檔架構

從 v2.0 開始，Pi-Paper-Clock 支援多設定檔功能，讓你可以在不同地點使用不同的設定。

---

## 🗂️ 設定檔結構

### 新版格式（v2.0+）

```json
{
  "global": {
    "ap_mode": { ... },
    "weather_api_key": "..."
  },
  "profiles": [ ... ],
  "active_profile": "設定檔名稱",
  "last_connected_profile": "設定檔名稱"
}
```

### 舊版格式（v1.x）自動遷移

如果你使用的是舊版 config.json，系統會在首次啟動時自動轉換為新格式：
- 舊設定會被保留並轉換為名為「預設」的設定檔
- 所有設定值都會保留
- 原始檔案會被覆寫為新格式

---

## 📦 設定項目說明

### 1. Global 設定（全局設定，所有設定檔共用）

#### `global.ap_mode`
AP 模式（無法連接 WiFi 時的熱點模式）設定

| 欄位 | 類型 | 說明 | 預設值 |
|---|---|---|---|
| `ssid` | String | AP 模式的 SSID（網路名稱） | `"Pi_Clock_AP"` |
| `password` | String | AP 模式的密碼（至少 8 個字元） | `"12345678"` |

#### `global.weather_api_key`
OpenWeatherMap API 金鑰（所有設定檔共用同一個 API Key）

| 類型 | 說明 | 取得方式 |
|---|---|---|
| String | OpenWeatherMap API 金鑰 | [https://openweathermap.org/api](https://openweathermap.org/api) |

---

### 2. Profiles 設定（設定檔陣列）

每個設定檔代表一個使用地點，包含該地點專屬的所有設定。

#### 設定檔結構

```json
{
  "name": "設定檔名稱",
  "wifi": { ... },
  "weather_location": "城市名稱",
  "user": { ... },
  "chime": { ... }
}
```

#### `profile.name`
設定檔名稱（唯一識別）

| 類型 | 說明 | 範例 |
|---|---|---|
| String | 設定檔的顯示名稱，不可重複 | `"家裡"`, `"公司"`, `"咖啡廳"` |

#### `profile.wifi`
WiFi 連線設定

| 欄位 | 類型 | 說明 |
|---|---|---|
| `ssid` | String | WiFi 網路名稱（SSID） |
| `password` | String | WiFi 密碼 |

**重要：** 系統會根據 WiFi SSID 自動識別並切換設定檔

#### `profile.weather_location`
天氣地點

| 類型 | 說明 | 範例 |
|---|---|---|
| String | OpenWeatherMap 支援的城市名稱 | `"Taipei"`, `"Zhonghe"`, `"Tokyo"` |

#### `profile.user`
使用者個人化設定

| 欄位 | 類型 | 說明 | 預設值 | 範圍 |
|---|---|---|---|---|
| `birthday` | String | 生日（MMDD 格式） | `"0101"` | `"0101"` ~ `"1231"` |
| `light_threshold` | Number | 光感臨界值（ADC 數值） | `56000` | `0` ~ `65535` |
| `image_interval_min` | Number | 圖片輪播間隔（分鐘） | `2` | `1` ~ `60` |
| `timezone_offset` | Number | 時區偏移（小時） | `8` | `-12` ~ `14` |

**光感臨界值說明：**
- 數值越低 = 越容易觸發螢幕休眠
- 建議在目標環境開燈時查看網頁中的「目前光感值」
- 設定為該值稍微大一點即可

#### `profile.chime`
定時響聲設定

| 欄位 | 類型 | 說明 | 預設值 | 選項/範圍 |
|---|---|---|---|---|
| `enabled` | Boolean | 是否啟用定時響聲 | `true` | `true` / `false` |
| `interval` | String | 響聲間隔 | `"hourly"` | `"hourly"` / `"half_hourly"` |
| `pitch` | Number | 音高（Hz） | `880` | `100` ~ `5000` |
| `volume` | Number | 音量（百分比） | `80` | `0` ~ `100` |

**響聲間隔：**
- `"hourly"`: 每小時整點響一次
- `"half_hourly"`: 每半小時響一次（整點 + 30 分）

---

### 3. 其他設定

#### `active_profile`
目前活動的設定檔名稱

| 類型 | 說明 |
|---|---|
| String | 系統目前使用的設定檔名稱，會自動更新 |

#### `last_connected_profile`
最後成功連接的設定檔名稱

| 類型 | 說明 |
|---|---|
| String 或 null | 記錄最後一次成功連接 WiFi 的設定檔，用於優先連接 |

---

## 🚀 使用方式

### 方法 1：透過網頁介面管理（推薦）

1. 長按時鐘上的按鈕 5 秒
2. 系統會重啟並進入 AP Mode
3. 連接到 WiFi：`Pi_Clock_AP`（或你設定的 AP SSID）
4. 開啟瀏覽器，前往 `192.168.4.1`
5. 在網頁介面中管理設定檔：
   - 新增設定檔
   - 編輯設定檔
   - 刪除設定檔
   - 切換活動設定檔

### 方法 2：手動編輯 config.json

1. 停止時鐘程式
2. 使用 `mpremote` 或其他工具編輯 `config.json`
3. 參考 `config.json.example` 格式
4. 重啟時鐘

---

## 🔄 自動切換設定檔

系統會在啟動時：

1. **掃描可用的 WiFi 網路**
2. **匹配已知設定檔** - 根據 WiFi SSID 尋找對應的設定檔
3. **智能連接順序**：
   - 優先嘗試上次成功連接的設定檔
   - 其他設定檔按信號強度排序嘗試
4. **自動切換** - 連接成功後，自動設定對應的設定檔為活動設定檔

### 範例場景

假設你有三個設定檔：「家裡」、「公司」、「咖啡廳」

**在家中：**
```
掃描到 "Home_WiFi"（家裡的 SSID）
  ↓
連接成功
  ↓
自動切換到「家裡」設定檔
  ↓
使用家裡的光感臨界值、響聲設定等
```

**帶到公司：**
```
掃描到 "Office_WiFi"（公司的 SSID）和其他網路
  ↓
上次成功是「家裡」，但這裡沒有 "Home_WiFi"
  ↓
找到「公司」設定檔（匹配 Office_WiFi）
  ↓
連接成功
  ↓
自動切換到「公司」設定檔
  ↓
使用公司的設定（關閉響聲、延長圖片間隔等）
```

---

## ⚙️ 完全重置

如果系統出現問題需要恢復出廠設定：

1. 長按按鈕進入 AP Mode
2. 連接到 AP 並開啟網頁介面
3. 滾動到最下方「⚠️ 危險區域」
4. 點擊「🔥 完全重置系統」
5. 輸入 `RESET` 確認
6. 再次確認
7. 系統會刪除所有設定檔並恢復預設設定

**注意：** 完全重置會清空所有設定檔，此操作無法復原！

---

## 📝 範例設定檔

參考 `config.json.example` 檔案，其中包含三個範例設定檔：

- **家裡**：啟用響聲，正常圖片間隔
- **公司**：關閉響聲，延長圖片間隔
- **咖啡廳**：啟用響聲，較低光感臨界值（環境較暗）

---

## 🔧 進階設定

### 自訂 AP Mode 設定

在網頁介面的「全局設定」區域可以修改：
- AP 模式的 SSID
- AP 模式的密碼

修改後下次進入 AP Mode 會使用新的設定。

### Weather API Key

Weather API Key 在所有設定檔之間共用，只需要設定一次。

網頁介面中 API Key 欄位預設為唯讀，需要連點 7 次才能編輯（防止誤觸）。

---

## ❓ 常見問題

### Q: 舊版 config.json 會被刪除嗎？
A: 會被自動轉換為新格式並覆寫，但所有設定都會保留。

### Q: 可以有多個設定檔使用同一個 WiFi SSID 嗎？
A: 不建議。系統會根據 SSID 識別設定檔，如果有重複會使用第一個匹配的。

### Q: AP Mode 超時後會發生什麼？
A: 系統會切換到最後一次連接的設定檔並重啟時鐘。

### Q: 可以手動切換設定檔嗎？
A: 可以透過網頁介面編輯任一設定檔並儲存，該設定檔會自動成為活動設定檔。

### Q: 刪除設定檔有限制嗎？
A: 系統至少需要保留一個設定檔，無法刪除最後一個。

---

## 📚 相關資源

- [OpenWeatherMap API 文件](https://openweathermap.org/api)
- [MicroPython 文件](https://docs.micropython.org/)
- [專案 GitHub](https://github.com/your-repo/pi-paper-clock)

---

**版本：** 2.0
**更新日期：** 2025-12-30

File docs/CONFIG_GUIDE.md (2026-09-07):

# Pico Paper Clock 設定檔說明

## 📋 多設定檔架構

從 v2.0 開始，Pico Paper Clock 支援多設定檔功能，讓你可以在不同地點使用不同的設定。

---

## 🗂️ 設定檔結構

### 新版格式（v2.0+）

```json
{
  "schema_version": 4,
  "global": {
    "ap_mode": { ... },
    "discord_webhook_url": "...",
    "setup_complete": false,
    "lan_admin": { "username": "admin", "password": "" }
  },
  "profiles": [ ... ],
  "active_profile": "設定檔名稱",
  "last_connected_profile": "設定檔名稱"
}
```

`schema_version` 由裝置維護。啟動時會補齊 v4 必要欄位並將硬體相關數值限制在文件範圍；保存使用 `config.json.tmp`／`.bak` 交易，意外斷電後會自動復原。請勿手動降低版本號。

若 `config.json` 的 `schema_version` 大於目前韌體支援的版本（例如被較新版本寫入後降級韌體），裝置會進入唯讀相容模式：略過遷移與正規化，且拒絕任何保存操作，直到韌體升級或版本號還原為止。

### 舊版格式（v1.x）自動遷移

如果你使用的是舊版 config.json，系統會在首次啟動時自動轉換為新格式：
- 舊設定會被保留並轉換為名為「預設」的設定檔
- 所有設定值都會保留
- 原始檔案會被覆寫為新格式

---

## 📦 設定項目說明

### 1. Global 設定（全局設定，所有設定檔共用）

#### `global.ap_mode`
AP 模式（無法連接 WiFi 時的熱點模式）設定

| 欄位 | 類型 | 說明 | 預設值 |
|---|---|---|---|
| `ssid` | String | AP 模式的 SSID（網路名稱） | `"Pi_Clock_AP"` |
| `password` | String | AP 模式的密碼（至少 8 個字元） | `"12345678"` |

#### 其他全域設定

| 欄位 | 用途 | 注意事項 |
|---|---|---|
| `global.discord_webhook_url` | 選用的 Discord 在席通知 webhook | 視為 secret；留空可停用通知 |
| `global.env_log.enabled` | 是否記錄溫濕度歷史（DHT22） | 預設 `true`；目前僅能透過 `config.json` 調整，Web UI 尚未提供切換開關 |
| `global.env_log.interval_min` | 溫濕度原始取樣間隔（分鐘） | 預設 `15`；目前僅能透過 `config.json` 調整，Web UI 尚未提供輸入欄位 |
| `global.setup_complete` | 是否已完成首次 Wi-Fi 設定；裝置也會依既有 profile 自動補正 | 一般不要手動修改 |
| `global.lan_admin.username` | WebUI session 固定登入帳號 | 固定為 `admin`；保留此欄位作舊設定相容性 |
| `global.lan_admin.password` | PBKDF2-HMAC-SHA256 密碼記錄，不是明文密碼 | 不要提交真實密碼或雜湊記錄 |

Web UI 對 secret 欄位只顯示「已設定」狀態；留白保存時會保留原值。裝置使用自訂登入頁與 server-side 單一 session，不使用 HTTP Basic Auth。LAN 設定與圖片 API 的認證細節請見 [`IMAGE_API.md`](IMAGE_API.md)。

---

### 2. Profiles 設定（設定檔陣列）

每個設定檔代表一個使用地點，包含該地點專屬的所有設定。

#### 設定檔結構

```json
{
  "name": "設定檔名稱",
  "wifi": { ... },
  "weather_latitude": 25.0330,
  "weather_longitude": 121.5654,
  "user": { ... },
  "chime": { ... }
}
```

#### `profile.name`
設定檔名稱（唯一識別）

| 類型 | 說明 | 範例 |
|---|---|---|
| String | 設定檔的顯示名稱，不可重複 | `"家裡"`, `"公司"`, `"咖啡廳"` |

#### `profile.wifi`
WiFi 連線設定

| 欄位 | 類型 | 說明 |
|---|---|---|
| `ssid` | String | WiFi 網路名稱（SSID） |
| `password` | String | WiFi 密碼 |

**重要：** 系統會根據 WiFi SSID 自動識別並切換設定檔

#### `profile.weather_latitude` / `profile.weather_longitude`
天氣查詢位置的緯度與經度。每個 profile 可使用不同座標；裝置會將座標直接傳給 Open-Meteo，並使用該 profile 的固定 `timezone_offset` 產生預報日期。

| 欄位 | 類型 | 範圍 | 範例 |
|---|---|---|---|
| `weather_latitude` | Number | `-90` ~ `90` | `25.0330` |
| `weather_longitude` | Number | `-180` ~ `180` | `121.5654` |

Open-Meteo 提供目前天氣與 5 天每日預報，不需要 API Key。WMO 天氣代碼會對應到裝置既有的天氣圖示；若網路或 API 暫時不可用，裝置沿用快取有效期限與日期／時間／圖片頁面的 fallback 行為。設定頁的地圖由瀏覽器延遲載入 Leaflet 與 OpenStreetMap 圖磚；地圖程式、圖磚與地圖資料不會儲存在 Pico W，也不會經由 Pico W 代理。瀏覽器無法連到地圖服務時，仍可直接輸入經緯度。

從舊版城市名稱遷移時，裝置只會離線對應內建的少數既有範例城市。無法對應的舊值會暫存於 `legacy_weather_location` 作為人工恢復提示，並先使用台北預設座標；此欄位不會被韌體拿來查詢天氣，請在設定頁填入正確座標後即可移除它。

#### `profile.user`
使用者個人化設定

| 欄位 | 類型 | 說明 | 預設值 | 範圍 |
|---|---|---|---|---|
| `birthday` | String | 生日（MMDD 格式） | `"0101"` | `"0101"` ~ `"1231"` |
| `light_threshold` | Number | 光感臨界值（ADC 數值） | `56000` | `0` ~ `65535` |
| `presence_leave_timeout_sec` | Number | 光感持續多久才判定離開書桌（秒） | `180` | `60` ~ `3600` |
| `presence_return_timeout_sec` | Number | 光感持續多久才恢復在席（秒） | `10` | `0` ~ `60` |
| `image_interval_min` | Number | 圖片輪播間隔（分鐘） | `2` | `1` ~ `60` |
| `timezone_offset` | Number | 時區偏移（小時） | `8` | `-12` ~ `14` |

**光感臨界值說明：**
- 數值越低 = 越容易觸發螢幕休眠
- 建議在目標環境開燈時查看網頁中的「目前光感值」
- 設定為該值稍微大一點即可

**離開書桌判定說明：**
- 光感低於或等於臨界值時立即判定在桌前
- 光感高於臨界值必須連續達到 `presence_leave_timeout_sec` 秒，才會判定離開書桌
- 回到臨界值以內必須連續達到 `presence_return_timeout_sec` 秒，才會恢復在桌前狀態
- `presence_return_timeout_sec` 設為 `0` 時，回到臨界值以內會立即恢復在席
- 只要處於離開書桌狀態、且韌體本次尚未對電子紙下過清屏睡眠指令，就會執行一次全白刷新並送入睡眠，直到偵測到返回在席才恢復正常時間／圖片更新。判準是**狀態**而非轉換的瞬間，因此在暗處重新開機（開機畫面已經畫上面板、但從頭就是離席狀態、沒有「剛剛離開」這個轉換）也會照樣清屏睡眠
- 離席期間收到的圖片預覽請求會被丟棄而不繪製：韌體已對面板下過睡眠指令且環境無光，畫上去也看不見，只會把面板重新叫醒。API 仍會照常回傳 `preview_queued: true`，但該次預覽不會顯示

#### `profile.chime`
定時響聲設定

| 欄位 | 類型 | 說明 | 預設值 | 選項/範圍 |
|---|---|---|---|---|
| `enabled` | Boolean | 是否啟用定時響聲 | `true` | `true` / `false` |
| `interval` | String | 響聲間隔 | `"hourly"` | `"hourly"` / `"half_hourly"` |
| `pitch` | Number | 音高（Hz） | `880` | `100` ~ `5000` |
| `volume` | Number | 音量（百分比） | `80` | `0` ~ `100` |

**響聲間隔：**
- `"hourly"`: 每小時整點響一次
- `"half_hourly"`: 每半小時響一次（整點 + 30 分）

---

### 3. 其他設定

#### `active_profile`
目前活動的設定檔名稱

| 類型 | 說明 |
|---|---|
| String | 系統目前使用的設定檔名稱，會自動更新 |

#### `last_connected_profile`
最後成功連接的設定檔名稱

| 類型 | 說明 |
|---|---|
| String 或 null | 記錄最後一次成功連接 WiFi 的設定檔，用於優先連接 |

---

## 🚀 使用方式

### 方法 1：透過網頁介面管理（推薦）

1. 長按時鐘上的任一按鈕約 3 秒
2. 系統會重啟並進入 AP Mode
3. 連接到 WiFi：`Pi_Clock_AP`（或你設定的 AP SSID）
4. 開啟瀏覽器，前往 `192.168.4.1`
5. 首次進入先設定固定管理帳號 `admin` 的至少 8 字元密碼；之後以 session 登入 WebUI
6. 在網頁介面中管理設定檔：
   - 新增設定檔
   - 編輯設定檔
   - 刪除設定檔
   - 切換活動設定檔

管理介面目前使用 HTTP。即使 session cookie 不再於每次 request 傳送密碼，同網段主動攻擊者仍可能攔截並重放 cookie 或 CSRF token；請只在可信任的 AP/LAN 使用。

### 方法 2：手動編輯 config.json

1. 停止時鐘程式
2. 使用 `mpremote` 或其他工具編輯 `config.json`
3. 參考 `config.json.example` 格式
4. 重啟時鐘

---

## 🔄 自動切換設定檔

系統會在啟動時：

1. **掃描可用的 WiFi 網路**
2. **匹配已知設定檔** - 根據 WiFi SSID 尋找對應的設定檔
3. **智能連接順序**：
   - 優先嘗試上次成功連接的設定檔
   - 其他設定檔按信號強度排序嘗試
4. **自動切換** - 連接成功後，自動設定對應的設定檔為活動設定檔

### 範例場景

假設你有三個設定檔：「家裡」、「公司」、「咖啡廳」

**在家中：**
```
掃描到 "Home_WiFi"（家裡的 SSID）
  ↓
連接成功
  ↓
自動切換到「家裡」設定檔
  ↓
使用家裡的光感臨界值、響聲設定等
```

**帶到公司：**
```
掃描到 "Office_WiFi"（公司的 SSID）和其他網路
  ↓
上次成功是「家裡」，但這裡沒有 "Home_WiFi"
  ↓
找到「公司」設定檔（匹配 Office_WiFi）
  ↓
連接成功
  ↓
自動切換到「公司」設定檔
  ↓
使用公司的設定（關閉響聲、延長圖片間隔等）
```

---

## ⚙️ 完全重置

如果系統出現問題需要恢復出廠設定：

1. 長按按鈕進入 AP Mode
2. 連接到 AP 並開啟網頁介面
3. 滾動到最下方「⚠️ 危險區域」
4. 點擊「🔥 完全重置系統」
5. 輸入 `RESET` 確認
6. 再次確認
7. 系統會刪除所有設定檔並恢復預設設定

**注意：** 完全重置會清空所有設定檔，此操作無法復原！

---

## 📝 範例設定檔

參考 `config.json.example` 檔案，其中包含三個範例設定檔：

- **家裡**：啟用響聲，正常圖片間隔
- **公司**：關閉響聲，延長圖片間隔
- **咖啡廳**：啟用響聲，較低光感臨界值（環境較暗）

---

## 🔧 進階設定

### 自訂 AP Mode 設定

在網頁介面的「全局設定」區域可以修改：
- AP 模式的 SSID
- AP 模式的密碼

修改後下次進入 AP Mode 會使用新的設定。

---

## ❓ 常見問題

### Q: 舊版 config.json 會被刪除嗎？
A: 會被自動轉換為新格式並覆寫。已知範例城市會轉成座標；無法離線對應的舊地點會保存在 `legacy_weather_location`，並先使用台北預設座標，避免靜默遺失資料。

### Q: 可以有多個設定檔使用同一個 WiFi SSID 嗎？
A: 不建議。系統會根據 SSID 識別設定檔，如果有重複會使用第一個匹配的。

### Q: AP Mode 超時後會發生什麼？
A: 系統會切換到最後一次連接的設定檔並重啟時鐘。

### Q: 可以手動切換設定檔嗎？
A: 可以透過網頁介面編輯任一設定檔並儲存，該設定檔會自動成為活動設定檔。

### Q: 刪除設定檔有限制嗎？
A: 系統至少需要保留一個設定檔，無法刪除最後一個。

### Q: Discord 通知突然不再送出了，怎麼查？
A: 先看裝置上的 `discord_diag.log`（可用 `mpremote connect COM<n> cat :discord_diag.log` 讀取），每行格式為 `日期,時間,事件,可用記憶體,細節`：

- `fail,...,lowmem,n=<次數>,largest=<最大連續區塊>`：heap 碎片化，連續記憶體不足以完成 TLS handshake。這是已知限制，pending 通知不會遺失。實測穩態下最大連續區塊只有約 10 KiB（門檻 20 KiB），送出幾乎只發生在重開機後的低記憶體啟動窗口，因此裝置會在連續失敗達門檻後自動重開機取回連續記憶體。**門檻依當下在席狀態而定**：離席（面板已清屏睡眠）時 2 次，約 2 分鐘；在席、或開機後第一次在席判定出來之前，則為 10 次、約 10 分鐘——重開機在你面前發生時要付出等待開機畫面的代價，離席時則幾乎無感。**保底重啟需同時滿足下列條件，任一不成立就不會重啟，這是刻意的 fail-safe 而非故障**：仍有 pending 通知、pending 已成功寫入 flash、開機已滿 5 分鐘、距上次自動重啟已滿 2 小時、且重啟時間戳能寫入 `discord_autoreset.log`。條件齊備時通常在該筆記錄後數分鐘內會看到 `autoreset` 與隨後送達的通知；若遲遲沒有，先依上述條件逐項確認，不要直接判定功能失效。
- `fail,...,http<狀態碼>`：webhook 本身的問題（例如 `http404` 代表 webhook 已被刪除、`http429` 代表被限流），請檢查 `global.discord_webhook_url`。**這類失敗不會觸發自動重啟**，需要你手動處理。
- `fail,...,offline` / `fail,...,nowebhook`：分別代表當下沒有網路連線、以及尚未設定 webhook；同樣不會觸發自動重啟。
- `recovered,...,after=<次數>`：先前失敗後已恢復送出。
- `autoreset,...,failures=<次數>,<away|present>`：曾觸發保底自動重啟。末欄是觸發當下的在席狀態，也就是套用了哪一個門檻（`away`＝2 次、`present`＝10 次）；沒有它就無法判斷失敗次數是否合乎預期。**這類重啟之後不會再送「已上線」通知**（若 IP 未變）——那次重啟唯一能用的 TLS 窗口要留給積壓的在席通知，不是拿來重報一個你已經知道的位址。IP 真的變了、或你自己斷電重開，則照常送出。

注意 `/api/v1/device` 回報的 `heap_free` 充足**不代表** Discord 送得出去，關鍵指標是最大連續區塊。

---

## 📚 相關資源

- [Open-Meteo API 文件](https://open-meteo.com/en/docs)
- [MicroPython 文件](https://docs.micropython.org/)
- [專案 GitHub](https://github.com/Ning0612/pico-paper-clock)

---

**版本：** 4.0（schema v4）
**更新日期：** 2026-07-17

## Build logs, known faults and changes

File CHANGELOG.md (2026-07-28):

# Changelog

所有此專案的顯著變更將會記錄在此檔案。

格式遵循 [Keep a Changelog](https://keepachangelog.com/en/1.0.0/)，
且本專案遵循 [Semantic Versioning](https://semver.org/spec/v2.0.0.html)。

## [2.6.1] - 2026-07-28

本版本把 v2.6.0 引入的 Discord 保底自動重啟機制修到堪用：縮短離席時的恢復延遲、補上三個會讓保底重啟失效或反而害死主程式的容錯缺陷，並停止把重啟換來的唯一 TLS 窗口浪費在重發使用者早已知道的 IP 上。

### Fixed

- 修正在無光環境重新開機後，電子紙停留在開機畫面且**永遠不進入睡眠**的問題。`main.py` 會在建立 controller 前無條件畫出開機畫面，而主迴圈原本只在偵測到「在席→離席」的轉換時才清屏睡眠；暗處開機時第一輪就已是離席狀態，不存在該轉換，於是開機畫面留在面板上、電子紙持續保持喚醒直到使用者開燈。面板長時間不睡眠是 Waveshare 明確不建議的用法，比畫面卡住本身更需要處理。此路徑原本罕見，但 Discord 記憶體保底重啟使「暗處開機」成為常態（離席＝變暗＝觸發通知＝送不出去＝約 2 分鐘後重啟），兩者相乘後每晚都會發生。修法是把離席顯示收斂由轉換驅動改為**狀態驅動**：`AppState` 新增 `display_asleep` 旗標（初值 `False`，因為開機畫面已經畫上面板），主迴圈只要處於離席且旗標未設就清屏睡眠並設起旗標，在席時清掉旗標，使所有進入離席的路徑收斂到同一個終態。
- 修正圖片預覽的 early return 會短路整輪主迴圈的問題。`consume_preview()` 命中時原本會立刻 `return`，因此客戶端只要每輪送一次 `preview=true`（批次上傳做得到），就能讓 `presence.update()`（連帶離席 debounce）、環境取樣、按鈕處理與 `_check_discord_stall()` 在整段期間完全不執行；離席期間畫上的預覽也會讓面板一直醒著。現在預覽改為在迴圈開頭消耗、在在席分支繪製，**只取代該輪的頁面渲染**，迴圈其餘部分照常跑完；預覽不更新 `last_minute`／`partial_update`，下一個觸發點即恢復正常頁面。離席時預覽直接丟棄不繪製——面板已睡眠且環境無光，畫上去看不見，只會把面板叫醒。

- 修正離席清屏睡眠失敗會終止整個主程式的問題。`main.py` 以 `while True: controller.run_main_loop()` 裸迴圈驅動、未包 try/except，因此 `clear_display_and_sleep()` 拋出的例外（低 heap、電子紙 I/O 失敗）會直接結束程式；而它正好位於 `_check_discord_stall()` 之前，於是最需要保底重啟的時刻反而永遠等不到重啟。現在改為捕捉例外並以 `DISPLAY_SLEEP_RETRY_MS`（60 秒）退避後重試——完整清屏加面板初始化太昂貴，每秒重試會排擠 LAN polling、presence 更新與 stall 檢查。此路徑在本次改動後更關鍵：暗處重開機必定會走一次離席分支。
- 修正 `discord_autoreset.log` 讀取失敗或內容損毀時冷卻機制失效的問題。原本任何讀取例外都回傳「允許重啟」，等同放棄唯一的 boot-loop 防護；離席門檻縮短為約 2 分鐘後，這會退化成每次 uptime gate 到期就重開一次。現在只有「檔案不存在」（ENOENT，代表從未自動重啟過）維持放行，其餘讀取錯誤與時鐘不可用一律拒絕；檔案存在但內容不可用（不可解析或 `<= 0`）時則重寫一個新的時間戳並拒絕本次重啟，重寫也失敗就設起 `auto_reset_blocked`，與呼叫端寫入失敗時的處置一致。
- 修正 NTP 同步失敗的開機會讓保底自動重啟被永久封鎖的問題。Pico W 沒有電池供電的 RTC，NTP 失敗時 `time.time()` 會從 port epoch 重新起算，而 `discord_autoreset.log` 內是由已同步開機寫下的大 epoch 值，兩者相減恆為負，冷卻判斷因此永遠不成立——保底重啟一路失效到 NTP 再次成功為止。現在偵測到時間戳比當下時鐘還新時，改為重寫成當下時基並拒絕本次重啟（等滿一次冷卻）；直接視為「已到期」則會每輪放行，而每次重啟又重置時基，形成 boot loop。

### Changed

- 縮短 Discord 通知堵塞後的恢復延遲：保底自動重啟門檻由「連續 30 次記憶體失敗」改為**依在席狀態選擇**——離席 `DISCORD_STALL_AWAY_FAILURES`（2 次，約 2 分鐘）、在席或狀態未知 `DISCORD_STALL_PRESENT_FAILURES`（10 次，約 10 分鐘）。依據為 2026-07-26 的實機複測：穩態下最大連續區塊僅約 10 KiB，只有 20 KiB 門檻的一半，且 `release_display_workspace()` 只增加 `mem_free`（56,512→61,584 B）而**完全不改變最大連續區塊**（前後同為 10,240 B）。既然等待不會改變結果，門檻改由「重開機當下的代價」決定：`presence_manager` 只在「離開書桌」的 transition 產生 pending session summary，因此幾乎所有待送通知誕生時裝置都正好離席、面板已清屏睡眠、使用者不在場，重開成本接近零；在席時重開則要讓使用者盯著開機畫面等 Wi-Fi 重連與 NTP 同步，故維持較慢的門檻。在席門檻刻意不設為「永不」——光感若把亮著的空房間誤判為在席，only-away 觸發會讓通知卡得比改動前更久。取捨已知：heap 若在第 3–9 次之間恢復，離席門檻會比舊門檻多一次重啟；上述量測取自單一裝置的 `.mpy` 部署，其他部署模式需重新量測。冷卻維持 2 小時以保留 boot-loop 防護，因此**吞吐上限未變**（冷卻為 per-reboot，且 `flush_startup_discord()` 每次開機最多清 8 筆），縮短的是單則通知的等待。
- 自動重啟的觸發判斷由「失敗數為門檻的整數倍」改為 `stall_checked_failures`／`stall_checked_threshold` latch：同一組（失敗數，門檻）只評估一次（冷卻檔因此仍維持每次失敗才讀一次，而非每輪主迴圈都讀），失敗數或門檻任一改變就重新評估。這是門檻可隨狀態變動的前提——使用者離開書桌使門檻下降時必須立即重評，而非等到下一次失敗；同時消除了原本「被 uptime gate 或冷卻擋掉一次就得等到下一個倍數、延遲加倍」的耦合。`DISCORD_STALL_MIN_UPTIME_MS` 維持 5 分鐘，但不再需要與門檻對齊，只需長於啟動通知窗口加一次重試。
- `discord_diag.log` 的 `autoreset` 記錄與對應 console 訊息加註觸發當下的在席狀態（`away`／`present`），否則事後無法把失敗次數對回是哪一個門檻。
- 因記憶體不足自動重開機後，若 LAN IP 與重啟前相同，開機不再送出「已上線」通知。那次重啟買到的是唯一一個可用的 TLS 窗口，而啟動階段原本第一件事就是重發一則使用者早已知道的 IP 通知，把窗口用掉、pending 在席通知只能再等下一次重啟（至少 2 小時）。現在 `_check_discord_stall()` 會在 `machine.reset()` 前把當下**已公告過**的 IP 寫入 `discord_autoreset_ip.log`，`main.py` 在啟動窗口讀取後立即刪除：IP 相同就跳過通知並標記為已送（避免 controller 每 30 秒重試），把窗口讓給 `flush_startup_discord()`。只有確實送出過的 IP 會被記錄——從未公告成功的位址仍照常嘗試，否則使用者根本無從得知裝置在哪；記錄採讀取即消費（且在「是否連上網路」判斷之外執行，避免一次沒連上線的開機把記錄留給後面某次本該公告的開機；刪除失敗時視為未消費並照常公告），因此手動斷電重開或 IP 真的改變時都會照常送出。

### Added

- `tests/test_app_controller.py` 新增 `test_a_touch_landing_on_a_preview_pass_is_not_swallowed`，斷言預覽輪的觸控仍會傳給 `handle_touch()`。`get_touch_state()` 會從驅動層取走事件且不會在下一輪重播，因此改為每輪讀取觸控之後，觸控處理必須與渲染分支解耦，否則預覽剛好落在同一輪時會吞掉一次圖片切換。
- `tests/test_app_controller.py` 新增保底重啟的防迴歸測試：`test_no_reset_at_the_away_threshold_while_present` 與 `test_unknown_presence_uses_the_present_threshold`（在席與狀態未知時不得套用離席門檻）、`test_reset_still_fires_while_present_at_the_slower_threshold`（在席安全網仍在，光感誤判時不會永遠卡住）、`test_leaving_the_desk_re_evaluates_a_count_already_checked`（門檻下降立即重評，不等下一次失敗）、`test_cooldown_file_is_read_once_per_failed_attempt` 與 `test_a_count_that_restarts_from_zero_is_checked_again`（latch 的節流與重置語意）、`test_reset_does_not_wait_for_a_multiple_of_the_threshold`（非倍數的失敗數同樣會觸發）、`test_a_pending_session_alone_is_enough_to_reboot`、`test_a_failing_panel_does_not_take_the_stall_check_down_with_it`（清屏失敗不得終止主迴圈）。`test_uptime_gate_outlasts_the_startup_window` 取代原本的倍數餘裕斷言，改為要求 uptime gate 長於啟動通知窗口加一次重試。
- `tests/test_app_controller.py` 新增四個顯示收斂的防迴歸測試：`test_starting_up_already_away_clears_and_sleeps_the_panel_once`（暗處開機時沒有轉換也要清屏睡眠，且只做一次）、`test_previews_arriving_while_away_never_bypass_the_away_branch`（離席期間的連續預覽不得喚醒已睡眠的面板）、`test_previews_while_present_do_not_starve_the_housekeeping`（在席期間的連續預覽不得讓 presence 更新、環境取樣與 stall 檢查停擺）、`test_unknown_presence_state_is_treated_as_away`（`current_state` 為 `None` 時 fail closed）。

## [2.6.0] - 2026-07-25

本版本修復 Discord 通知在裝置長時間運行後永久堵塞的問題，並將專案顯示名稱統一為 Pico Paper Clock。

### Fixed

- 修正 Discord 通知在裝置連續運行多日後永久送不出去、只有重開機才能恢復的問題。根因為 heap 碎片化：TLS handshake 需要一塊約 18–23 KiB 的**連續**記憶體，而裝置運行時 `gc.mem_free()` 雖有約 57 KiB，最大連續區塊卻僅約 17.9 KiB。實機量測顯示最大連續區塊為 17,920 B 時 `ssl.wrap_socket` 直接拋出 `OSError [Errno 12] ENOMEM`，23,120 B 時才成功；既有的 `release_display_workspace()` 僅能多騰出約 5.2 KiB，安全邊際極薄。舊版 `flush_discord()` 在 ENOMEM 後只會每 60 秒無限重試，沒有任何逃生路徑。
- 修正 `send_presence_summary()` 丟棄 Discord HTTP 錯誤回應內容的問題，失敗時無法得知實際原因；現與其他兩個送信函式一致會記錄回應內容。

### Added

- `discord_notifier.py` 新增 TLS 記憶體探針 `has_tls_headroom()` 與 `largest_contiguous_block()`。`presence_manager.flush_discord()` 在釋放顯示工作區之後、送信之前執行 pre-flight 檢查，連續記憶體低於 `TLS_MIN_CONTIGUOUS_BYTES`（20 KiB）時直接跳過本次嘗試，避免耗費約 3 秒在必定失敗的 TLS handshake 上。記憶體探針之前會先以新增的 `delivery_blocked()` 判斷 webhook 是否設定、網路是否連線，確保「未設定 webhook」或「斷網」不會被誤記為記憶體不足而觸發幫不上忙的重開機；三個送信函式共用同一份判斷。
- 新增持久化診斷日誌 `discord_diag.log`（上限 6 KiB，超過時以串流方式捨棄較舊的一半，並比照既有 `_commit_tmp` 以 `.bak` 交換，斷電時必留一份可讀副本）。記錄送信失敗原因、當下可用記憶體與最大連續區塊，讓失敗不再只 `print` 到 UART 而在斷電後遺失。記錄採節流策略：第 1 次失敗與其後每 10 次各記一筆。失敗原因分為 `lowmem`／`enomem`（記憶體）與 `http<狀態碼>`／`offline`／`nowebhook`／`badformat`／`baddata`（非記憶體），可直接判讀故障類型。
- 新增保底自動重啟：**僅限記憶體類失敗**（pre-flight `lowmem` 與送信 `ENOMEM`）連續達 30 次、仍有 pending 通知、且開機已滿 10 分鐘時執行 `machine.reset()`，藉由重開機取回連續 heap。HTTP 錯誤、斷網、未設定 webhook 等非記憶體失敗會將此計數歸零，不會觸發重啟——重開機無法修好一個被刪除的 webhook。多重防護：pending 通知未能寫入 flash 時放棄重啟（避免遺失）；冷卻時間戳無法持久化時同樣放棄重啟（fail-safe，避免退化成 boot loop）；`discord_autoreset.log` 的時間戳在執行期即時評估，2 小時內不重複自動重啟。開機滿 10 分鐘的判定採用 latch，因為 MicroPython 的 `ticks_diff()` 僅在約 ±6.2 天內有效，而本次故障正好出現在約 12 天的運行之後。

### Changed

- 專案顯示名稱統一為 Pico Paper Clock，移除文件、Web UI 頁面、桌面工具與 Discord 上線通知中殘留的舊名 Pi Paper Clock。
- `GET /api/v1/device` 回傳的裝置識別字串由 `pi-paper-clock` 改為 `pico-paper-clock`。桌面圖片工具同時接受新舊兩種識別字串，因此尚未更新韌體的裝置仍可正常連線。

## [2.5.0] - 2026-07-22

### Added

- 新增環境（溫濕度）歷史記錄功能：`env_manager.py` 預設每 15 分鐘（可透過 `global.env_log.interval_min` 調整）取樣一次 DHT22，原始樣本保留 7 天、每日彙總保留 366 天，離開書桌、螢幕休眠時仍持續記錄；比照 `presence_manager.py` 的交易式寫入與視窗式裁切模式。
- 新增獨立的環境紀錄 WebUI 頁面 `/environment`，含日/週/月/年趨勢圖切換、今日溫濕度統計卡片與每日統計表格，以及對應的 `/api/env/status`、`/api/env/samples`、`/api/env/daily` 串流 API（見 `docs/ENV_LOG_API.md`）。
- 新增 `tools/pico_deploy/upload_cli.py --mpy` opt-in 部署選項：部署前用 `mpy-cross` 將 `.py` 預編譯為 `.mpy` bytecode 節省裝置 flash（`epaper.py`／`main.py`／`config.json` 除外），同步加入桌面 GUI 勾選框；實測裝置剩餘 flash 從 88.0 KiB 提升到 204.0 KiB。
- Discord pending 通知佇列（`presence_pending.log`／`presence_session_pending.log`）新增 7 天保留視窗裁切，避免 webhook 長期失效時無限累積。

## [2.4.1] - 2026-07-21

### Fixed

- 修正 Discord 書桌前時段與每日統計通知在主迴圈建立 pending queue 後，被空 queue 的 cooldown 錯誤延後 flush 的問題。

## [2.3.0] - 2026-07-17

### Added

- 新增整合式 Pico Paper Clock 桌面 GUI，合併 USB/`mpremote` 資源部署、LAN/AP 圖片批次上傳、manifest 預覽與作業佇列。
- 新增完整同步流程：序列部署重啟後輪詢裝置網路，恢復連線後再執行圖片上傳。

### Changed

- 序列部署 manifest 與 mpremote 執行核心可由 GUI 與 `upload.py` 共用；GUI 預設不清理裝置、不覆寫 `config.json`。
- GUI 序列埠改為掃描後以下拉選單選取，WebUI 帳號固定為 `admin`；LAN discovery 改用 ARP 候選逐一探測並排除 link-local 網段，降低 Pico WebUI 被掃描壓垮的風險。
- 完整同步加入 Pico 重啟後的啟動寬限期與短 timeout 網路重試，適配實機 Wi-Fi／WebUI 初始化時間。
- PyInstaller 桌面工具改名為 `PicoPaperClockTool`，並保留 Python/CLI 入口。

### Fixed

- 修正 Pico WebUI 登入回應中 `Set-Cookie` header 變數覆蓋 JSON body，導致圖片工具收到 cookie 字串而無法建立 session 的問題。
- 修正 Linux CI runner 執行 Windows subprocess console-hide 測試時缺少 `STARTUPINFO` 造成的跨平台失敗。

## [2.2.0] - 2026-07-17

本版本聚焦於圖片工作流程、Pico W 記憶體穩定性、儲存空間使用量與 WebUI 使用體驗。

### Added

- 新增書桌前分析儀表板，提供即時在席狀態、24 小時/30 天統計、年度熱力圖、每日紀錄與最近時段。
- 新增登入、設定、書桌前分析與圖片庫的完整裝置 WebUI 流程。

### Changed

- 更新 Pico Image Tool 的圖片轉換、壓縮、預覽與認證上傳流程，並與裝置端圖片 API 的交易寫入和復原機制整合。
- 以可重用 buffer、串流處理、低記憶體 Discord queue flush 與 ENOMEM retry 降低啟動、網路、天氣和圖片操作的記憶體峰值。
- 新增 PPC1 圖片壓縮格式與 WebUI gzip 資產壓縮，降低圖片、天氣圖示與裝置 WebUI 的儲存空間使用量。
- 重新設計 AP/LAN WebUI，統一設定、圖片庫與分析頁面的視覺風格，並加入深色/淺色主題切換與更完整的響應式版面。
- 改善天氣預報顯示與書桌前分析的日期、熱力圖導覽及資料序列化。

### Documentation

- 更新 README 的專案定位與 WebUI 預覽，並歸檔四張 WebUI 截圖。

## [2.1.1] - 2026-07-13

- 修正 v3 外殼 STL Release asset，確保附件與 Git 歷史中追蹤的 `hardware/clock_v3.STL` 完全一致。
- 同步 Release asset 文件中的檔名、SHA-256 與下載連結。

## [2.1.0] - 2026-07-13

本版本發布目前 `Unreleased` 中的功能、穩定性修正與主機端圖片工具；UF2 與 v3 外殼的 STEP、STL、SLDPRT 檔案改由 GitHub Release assets 提供。

### Added
- 新增低記憶體圖片 API、`/images` 裝置管理頁與圖片交易復原。
- 新增 Pico Image Tool GUI/CLI、LAN 探索、四種抖動、三種 fit 與 Windows PyInstaller build 規格。
- 新增圖片格式與交易 golden tests。

### Changed
- AP/LAN Web server 共用同一 dispatcher；設定頁改用靜態 HTML 與版本化設定 API。
- 顯示改為單一 native framebuffer、逐列圖片讀取與批次 SPI 傳輸。
- 設定保存改為 schema v3 單次交易，presence pending queue 改為串流處理。
- 啟動網路流程改為先完成 Discord webhook，再載入顯示、硬體、天氣與 controller 工作路徑，降低 Pico W TLS 的記憶體配置峰值。
- Discord webhook 改用低配置 raw HTTPS socket，並在 partial write、socket close、GC 與 ENOMEM retry 上加入防護。
- DHT22 讀取加入 2500 ms 節流、失敗 10 秒 backoff 與舊值快取；天氣預報改用 256-byte buffer 和 `readinto()` 串流解析。
- 大型 UF2 與 CAD（`.SLDPRT`、`.step`、`.stl`）檔案移出 source tree，改由 GitHub Release assets 發布。

### Fixed
- `image_interval_min` 現在實際控制輪播間隔，日期事件圖片會依生日、MMDD、custom 優先序顯示。
- MONO_HLSB 明確採 bit 0 為左側像素，避免每 8 像素位元順序錯誤。
- 修復 Pico W 在 Discord webhook 與 presence 發送時的 `ENOMEM`：失敗不再中止啟動流程或永久丟棄 pending presence，並可在冷卻後重試。

## [2.0.1] - 2025-12-31

### 安全性修復 (Security)
- **🔒 安全性強化**：針對系統安全性進行全面修復與強化，包含防止跨站腳本攻擊 (XSS)、跨站請求偽造 (CSRF) 及敏感資訊保護，提升系統整體的防護能力。

## [2.0.0] - 2025-12-31

### 重大變更 (Breaking Changes)
- **設定檔格式升級**：`config.json` 採用新的多設定檔架構，支援為不同地點建立獨立設定檔（向後兼容舊格式）。
- **長按按鈕行為變更**：長按按鈕改為進入 AP 模式（不再清除設定檔），可透過網頁介面管理或重置。

### 新增功能 (Added)
- **多設定檔系統**：
  - 支援建立多個設定檔（如家裡、公司），每個設定檔包含獨立的 WiFi、天氣地點及裝置參數。
  - 全局設定（AP Mode、Weather API Key）在所有設定檔間共用。
- **智能 WiFi 連接**：啟動時自動掃描並根據 SSID 信號強度優先連接合適的設定檔。
- **網頁端管理介面**：
  - 全新雙欄式響應設計，支援新增、編輯、刪除設定檔。
  - 即時顯示光感應器數值與活動狀態。
  - 提供「完全重置」功能（位於危險區域）。

### 改進與優化 (Improved & Optimized)
- **UI/UX 全面升級**：
  - **響應式設計**：針對手機與桌機優化佈局，手機版採用原生下拉選單與單欄設計。
  - **視覺統一**：導入 CSS 變數系統、統一按鈕樣式、增強互動反饋（Loading 狀態、倒數動畫）。
  - **操作體驗**：優化設定檔選擇邏輯，編輯時自動定位，並以清晰標記（● 編輯中、(啟用)）顯示狀態。
- **系統核心優化**：
  - **AP 模式記憶體優化**：重構 Web 伺服器採用分塊傳送 (Chunked Sending) 與靜態資源壓縮，大幅降低記憶體佔用。
  - **傳輸穩定性**：實作 `send_chunk()` 機制並加入延遲，解決 Pico W 緩衝區溢位導致的頁面載入不完整問題。
  - **架構重構**：`config_manager` 與 `wifi_manager` 深度重構，提升程式碼可維護性與錯誤處理能力。

---

## [1.6.0] - 2025-08-14

### 變更與重構 (Changed & Refactored)
- **統一按鈕長按與重置邏輯**：
  - 將按鈕長按偵測邏輯集中到 `hardware_manager.py`，移除了 `app_controller.py` 中的重複實作。
  - 新增 `wifi_manager.py:reset_wifi_and_reboot()` 函式，統一處理 Wi-Fi 和 AP 模式的設定重置與裝置重啟流程。
  - 現在，無論在正常模式或 AP 模式下，長按任一按鈕 3 秒都會觸發一致的重置行為。
- **AP 模式穩定性與體驗優化**：
  - **動態超時機制**：AP 模式的閒置超時會因使用者活動（如客戶端連線、提交表單）而自動延長，防止在設定過程中意外重啟。
  - **支援在 AP 模式下按鈕重置**：即使在 AP 模式的網頁設定介面下，使用者依然可以透過長按按鈕來重置裝置。

### 修正 (Fixed)
- **設定一致性**：修正了 AP 模式預設 SSID 在不同檔案中不一致的問題，統一為 `Pi_Clock_AP`。

## [1.5.1] - 2025-08-01

### 修正 (Fixed)
- **天氣預報日期格式修正**：在 `display_manager.py` 中，修正了日期格式化問題。確保在與天氣預報資料比對時，單位數的日期會補零（例如 `7` -> `07`），避免在每月的前九天可能發生的當日天氣無法正確顯示在預報列表中的錯誤。

## [1.5.0] - 2025-07-29

### 新增功能 (Added)
- **AP 模式安全性強化**：
  - AP 模式的預設密碼長度提升至 8 個字元 (`12345678`)，並在 `config.json.example` 與 `config_manager.py` 中同步更新，增強初次設定的安全性。
- **AP 模式穩定性提升**：
  - **重構設定儲存邏輯**：在 `wifi_manager.py` 中，將原本分散的參數解析與設定儲存流程，重構為先將所有設定存入 `dict`，再統一寫入，提升程式碼可讀性與可維護性。
  - **新增錯誤處理頁面**：若使用者在 AP 設定頁面提交的表單資料不完整或格式錯誤，系統將顯示一個獨立的錯誤頁面，引導使用者返回修正，而不是直接崩潰或忽略錯誤。

## [1.4.0] - 2025-07-21

### 變更與重構 (Changed & Refactored)
- **程式碼品質提升**:
  - **全面英文化**：統一將所有模組 (`.py`) 中的註解與 `print()` 輸出訊息從中文改為英文，提升可讀性。
  - **新增 Docstrings**：為專案中所有主要類別與函式補上標準的 Docstrings，詳細說明其功能、參數與用途，大幅改善程式碼的可維護性。
- **Wi-Fi 與設定流程優化 (`wifi_manager.py`)**:
  - **重構設定儲存邏輯**：簡化 AP 模式下儲存設定的流程，改為直接呼叫 `config_manager.set()`，使程式碼更直觀且易於管理。
  - **縮短連線超時**：將 Wi-Fi 連線等待時間從 10 分鐘縮短至 1 分鐘，讓裝置在無法連線時能更快進入 AP 設定模式。
- **顯示邏輯整理 (`display_manager.py`)**:
  - 將 AP 模式的顯示邏輯從 `wifi_manager.py` 移至 `display_manager.py` 中，並建立 `update_display_AP` 函式，提高顯示相關程式碼的集中度。

### 清理 (Removed)
- **移除無用函式**：刪除了 `netutils.py` 中不再使用的 `load_wifi_config`, `save_wifi_config` 等輔助函式。
- **清理驅動程式碼**：移除了 `epaper.py` 中原廠提供但已註解的範例程式碼，保持檔案整潔。

## [1.3.1] - 2025-07-21

### 修正 (Fixed)
- **記憶體穩定性與系統優化**：
  - **天氣更新重構 (`weather.py`)**：徹底重構天氣預報 (`fetch_weather_forecast`) 的處理邏輯。改為分段讀取並逐塊解析 JSON 回應，僅提取必要欄位，避免一次性將大型資料載入記憶體，從根本上解決了 `MemoryError` 問題。
  - **積極的記憶體回收**：在 `weather.py` 和 `display_utils.py` 中的記憶體密集型操作（如 JSON 解析、圖片繪製）後，強制執行垃圾回收 (`gc.collect()`) 並手動釋放大型物件 (`del obj`, `obj = None`)，有效緩解了記憶體碎片化。
  - **優化更新調度 (`app_controller.py`)**：天氣更新由時間驅動，僅在固定間隔（當前天氣 3 分鐘，預報 30 分鐘）或資料不存在時觸發，避免了不必要的網路請求與計算，降低了系統負載。

## [1.3.0] - 2025-07-18

### 新增功能 (Added)
- **圖片管理增強**：
  - 新增日期特定事件圖片支援，可顯示與當前日期相關的圖片。
  - 觸控螢幕可循環切換圖片。
  - 載入頁面圖片現在會隨機顯示。

### 變更與重構 (Changed)
- **部署腳本優化 (`upload.py`)**：
  - 腳本已大幅重構，支援設備遞歸清理。
  - 上傳過程提供更詳細的進度報告（包含檔案大小）。
  - 改進目錄創建邏輯，避免重複的 `mkdir` 調用。
  - 移除 `get_device_space_info` 函數。
- **本地化與訊息統一**：
  - `src/app_controller.py` 和 `src/display_utils.py` 中的多處列印訊息和使用者介面字串已從中文改為英文。
- **工具改進 (`tools/image_to_bin.py`)**：
  - 轉換工具現在會保留原始檔案名稱作為預設儲存名稱。
- **版本控制忽略設定**：
  - `.gitignore` 已更新，忽略 `src/image` 目錄下的常見圖片格式 (`.jpg`, `.jpeg`, `.png`)。

## [1.2.0] - 2025-07-18

### 新增功能 (Added)
- **時區設定功能**：
  - 新增 `timezone_offset` 設定，允許使用者根據所在地區設定 UTC 時間偏移（-12 到 +14 小時）。
  - 可於 `config.json` 或 AP 模式設定頁面中進行設定。
  - 主畫面時間與天氣預報將根據此偏移量顯示正確的本地時間。

### 變更與重構 (Changed)
- **天氣模組記憶體優化**：
  - 重構 `weather.py` 中的天氣預報功能 (`fetch_weather_forecast`)，採用分段處理 JSON 資料的方式，大幅降低記憶體使用量，解決在記憶體有限的 Pico W 上可能發生的 `MemoryError`。
  - 增強 `_make_request_with_retry` 的錯誤處理，加入 `OSError` 和 `MemoryError` 的捕獲，並在請求前後手動觸發垃圾回收 (`gc.collect()`)。
- **設定檔結構調整**：
  - 在 `config.json` 中，將 `light_threshold` 和 `image_interval_min` 移至 `user` 物件下，使設定檔結構更清晰。
- **程式碼邏輯優化**：
  - `display_manager.py` 中的畫面更新函數現在直接接收時間物件，避免重複呼叫 `get_local_time()`。

## [1.1.0] - 2025-07-17

### 新增功能 (Added)
- **定時響聲功能**：
  - 新增 `chime.py` 模組，可透過無源蜂鳴器 (Pin 20) 實現整點或半點報時。
  - 可於 `config.json` 或 AP 模式設定頁面中啟用/停用、調整音調與音量。
- **AP 模式功能擴充**：
  - 設定頁面新增「定時響聲」相關選項。
  - 設定頁面會即時顯示當前光感應器的 ADC 數值，每 3 秒自動更新。
  - 新增 `/adc` API endpoint 供前端非同步取得感測器數值。
  - **新增「測試響聲」按鈕**：在 AP 模式設定頁面中，音量設定旁新增測試按鈕，可即時測試蜂鳴器響聲。

### 變更與重構 (Changed)
- **應用程式架構重構**：
  - 將原有的 `main.py` 核心邏輯拆分為多個獨立模組，包含 `app_controller.py`, `app_state.py`, `hardware_manager.py` 等，提高模組化與可維護性。
  - 遵循單一職責原則，各模組功能更專一。
- **統一設定管理**：
  - 引入 `config_manager.py` 模組，集中處理 `config.json` 的讀取與寫入，提供統一的設定存取介面。
  - `config.json` 擴充了響聲、生日、光感門檻等設定。
- **Web 設定介面優化**：
  - AP 模式的 HTML 頁面 (`wifi_manager.py`) 進行了重構，以支援更多設定選項與即時數據顯示。
  - **優化設定儲存流程**：調整 AP 模式下設定儲存流程，先解析並儲存設定，再回傳包含已儲存設定（敏感資料已遮蔽）的成功頁面，最後才重啟裝置。
  - **增加重啟延遲**：將設定儲存後的重啟延遲從 3 秒增加到 5 秒，確保客戶端能完整接收成功頁面。
- **按鈕行為優化**：
  - 在 `app_controller.py` 中實現按鈕長按偵測，長按可觸發 Wi-Fi 重置並重啟設備。
  - `hardware_manager.py` 中 `get_button_states` 方法調整，將按鈕原始值反轉，使 `1` 表示按下，`0` 表示未按下。
- **顯示函數重構**：
  - `update_display_Restart` 函數從 `wifi_manager.py` 移至 `display_manager.py`，統一顯示相關邏輯。
- **錯誤修正**：
  - 修正 `wifi_manager.py` 中 `success_page_template` 因 CSS 樣式中的 `{}` 未正確跳脫導致的 `KeyError: 'font-family'` 錯誤。
- **穩定性提升**：
  - 增強了 Wi-Fi 連線、天氣 API 請求及圖片載入時的錯誤處理機制，加入重試與 fallback 邏輯。
  - 移除 `chime.py` 中不再使用的 `test_chime` 函數。
  - **網路與檔案操作穩定性強化**：
    - 為天氣 API 請求 (於 `src/weather.py`) 實作了更穩健的重試機制，並改進了錯誤日誌，同時確保在無網路連線時跳過請求。
    - 在 NTP 時間同步 (於 `src/netutils.py`) 前增加網路連線檢查。
    - 改進了圖片載入 (於 `src/display_utils.py` 和 `src/file_manager.py`) 的錯誤處理，並將錯誤訊息翻譯為英文。
  - **`NoneType` 錯誤修正**：強化了 `urequests` 回應物件可能為 `None` 的錯誤處理邏輯，確保安全地關閉回應物件。
- **錯誤修正**：
  - 修正 `wifi_manager.py` 中 `success_page_template` 因 CSS 樣式中的 `{}` 未正確跳脫導致的 `KeyError: 'font-family'` 錯誤。
  - **訊息統一**：所有 `print` 訊息皆已轉換為英文。
- **內部邏輯調整**：
  - `src/app_controller.py` 中 `_perform_chime` 的呼叫順序調整。
  - `upload.py` 處理了 `UnicodeDecodeError` 並新增了顯示設備空間資訊的功能。

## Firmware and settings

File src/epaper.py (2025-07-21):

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

from machine import Pin, SPI, I2C
import framebuf
import utime

# Display resolution
EPD_WIDTH       = 128
EPD_HEIGHT      = 296
  
WF_PARTIAL_2IN9 = [
    0x0,0x40,0x0,0x0,0x0,0x0,0x0,0x0,0x0,0x0,0x0,0x0,
    0x80,0x80,0x0,0x0,0x0,0x0,0x0,0x0,0x0,0x0,0x0,0x0,
    0x40,0x40,0x0,0x0,0x0,0x0,0x0,0x0,0x0,0x0,0x0,0x0,
    0x0,0x80,0x0,0x0,0x0,0x0,0x0,0x0,0x0,0x0,0x0,0x0,
    0x0,0x0,0x0,0x0,0x0,0x0,0x0,0x0,0x0,0x0,0x0,0x0,
    0x0A,0x0,0x0,0x0,0x0,0x0,0x0,  
    0x1,0x0,0x0,0x0,0x0,0x0,0x0,
    0x1,0x0,0x0,0x0,0x0,0x0,0x0,
    0x0,0x0,0x0,0x0,0x0,0x0,0x0,
    0x0,0x0,0x0,0x0,0x0,0x0,0x0,
    0x0,0x0,0x0,0x0,0x0,0x0,0x0,
    0x0,0x0,0x0,0x0,0x0,0x0,0x0,
    0x0,0x0,0x0,0x0,0x0,0x0,0x0,
    0x0,0x0,0x0,0x0,0x0,0x0,0x0,
    0x0,0x0,0x0,0x0,0x0,0x0,0x0,
    0x0,0x0,0x0,0x0,0x0,0x0,0x0,
    0x0,0x0,0x0,0x0,0x0,0x0,0x0,
    0x22,0x22,0x22,0x22,0x22,0x22,0x0,0x0,0x0,
    0x22,0x17,0x41,0xB0,0x32,0x36,
]

WF_PARTIAL_2IN9_Wait = [
0x0,0x40,0x0,0x0,0x0,0x0,0x0,0x0,0x0,0x0,0x0,0x0,
0x80,0x80,0x0,0x0,0x0,0x0,0x0,0x0,0x0,0x0,0x0,0x0,
0x40,0x40,0x0,0x0,0x0,0x0,0x0,0x0,0x0,0x0,0x0,0x0,
0x0,0x80,0x0,0x0,0x0,0x0,0x0,0x0,0x0,0x0,0x0,0x0,
0x0,0x0,0x0,0x0,0x0,0x0,0x0,0x0,0x0,0x0,0x0,0x0,
0x0A,0x0,0x0,0x0,0x0,0x0,0x2,  
0x1,0x0,0x0,0x0,0x0,0x0,0x0,
0x1,0x0,0x0,0x0,0x0,0x0,0x0,
0x0,0x0,0x0,0x0,0x0,0x0,0x0,
0x0,0x0,0x0,0x0,0x0,0x0,0x0,
0x0,0x0,0x0,0x0,0x0,0x0,0x0,
0x0,0x0,0x0,0x0,0x0,0x0,0x0,
0x0,0x0,0x0,0x0,0x0,0x0,0x0,
0x0,0x0,0x0,0x0,0x0,0x0,0x0,
0x0,0x0,0x0,0x0,0x0,0x0,0x0,
0x0,0x0,0x0,0x0,0x0,0x0,0x0,
0x0,0x0,0x0,0x0,0x0,0x0,0x0,
0x22,0x22,0x22,0x22,0x22,0x22,0x0,0x0,0x0,
0x22,0x17,0x41,0xB0,0x32,0x36,
]

WS_20_30 = [					
0x80,0x66,0x0,0x0,0x0,0x0,0x0,0x0,0x40,0x0,0x0,0x0,
0x10,0x66,0x0,0x0,0x0,0x0,0x0,0x0,0x20,0x0,0x0,0x0,
0x80,0x66,0x0,0x0,0x0,0x0,0x0,0x0,0x40,0x0,0x0,0x0,
0x10,0x66,0x0,0x0,0x0,0x0,0x0,0x0,0x20,0x0,0x0,0x0,
0x0,0x0,0x0,0x0,0x0,0x0,0x0,0x0,0x0,0x0,0x0,0x0,
0x14,0x8,0x0,0x0,0x0,0x0,0x2,
0xA,0xA,0x0,0xA,0xA,0x0,0x1,
0x0,0x0,0x0,0x0,0x0,0x0,0x0,
0x0,0x0,0x0,0x0,0x0,0x0,0x0,
0x0,0x0,0x0,0x0,0x0,0x0,0x0,
0x0,0x0,0x0,0x0,0x0,0x0,0x0,
0x0,0x0,0x0,0x0,0x0,0x0,0x0,
0x0,0x0,0x0,0x0,0x0,0x0,0x0,
0x14,0x8,0x0,0x1,0x0,0x0,0x1,
0x0,0x0,0x0,0x0,0x0,0x0,0x1,
0x0,0x0,0x0,0x0,0x0,0x0,0x0,
0x0,0x0,0x0,0x0,0x0,0x0,0x0,
0x44,0x44,0x44,0x44,0x44,0x44,0x0,0x0,0x0,
0x22,0x17,0x41,0x0,0x32,0x36
]

Gray4 = [						
0x00,0x60,0x00,0x00,0x00,0x00,0x00,0x00,0x00,0x00,0x00,0x00,
0x20,0x60,0x10,0x00,0x00,0x00,0x00,0x00,0x00,0x00,0x00,0x00,
0x28,0x60,0x14,0x00,0x00,0x00,0x00,0x00,0x00,0x00,0x00,0x00,
0x2A,0x60,0x15,0x00,0x00,0x00,0x00,0x00,0x00,0x00,0x00,0x00,
0x00,0x90,0x00,0x00,0x00,0x00,0x00,0x00,0x00,0x00,0x00,0x00,
0x00,0x02,0x00,0x05,0x14,0x00,0x00,
0x1E,0x1E,0x00,0x00,0x00,0x00,0x01,
0x00,0x02,0x00,0x05,0x14,0x00,0x00,
0x00,0x00,0x00,0x00,0x00,0x00,0x00,
0x00,0x00,0x00,0x00,0x00,0x00,0x00,
0x00,0x00,0x00,0x00,0x00,0x00,0x00,
0x00,0x00,0x00,0x00,0x00,0x00,0x00,
0x00,0x00,0x00,0x00,0x00,0x00,0x00,
0x00,0x00,0x00,0x00,0x00,0x00,0x00,
0x00,0x00,0x00,0x00,0x00,0x00,0x00,
0x00,0x00,0x00,0x00,0x00,0x00,0x00,
0x00,0x00,0x00,0x00,0x00,0x00,0x00,
0x24,0x22,0x22,0x22,0x23,0x32,0x00,0x00,0x00,
0x22,0x17,0x41,0xAE,0x32,0x28		
]	

# e-Paper
RST_PIN         = 12
DC_PIN          = 8
CS_PIN          = 9
BUSY_PIN        = 13

# TP
TRST    = 16
INT     = 17

# key
KEY0 = 2
KEY1 = 3
KEY2 = 15

class config():
    def __init__(self, i2c_addr):
        self.reset_pin = Pin(RST_PIN, Pin.OUT)
        self.busy_pin = Pin(BUSY_PIN, Pin.IN)
        self.cs_pin = Pin(CS_PIN, Pin.OUT)

        self.trst_pin = Pin(TRST, Pin.OUT)
        self.int_pin = Pin(INT, Pin.IN)

        self.key0 = Pin(KEY0, Pin.IN, Pin.PULL_UP)
        self.key1 = Pin(KEY1, Pin.IN, Pin.PULL_UP)
        self.key2 = Pin(KEY2, Pin.IN, Pin.PULL_UP)
        
        self.spi = SPI(1)
        self.spi.init(baudrate=4000_000)
        self.dc_pin = Pin(DC_PIN, Pin.OUT)

        self.address = i2c_addr
        self.i2c = I2C(1, scl=Pin(7), sda=Pin(6), freq=100_000)

    def digital_write(self, pin, value):
        pin.value(value)

    def digital_read(self, pin):
        return pin.value()

    def delay_ms(self, delaytime):
        utime.sleep(delaytime / 1000.0)

    def spi_writebyte(self, data):
        self.spi.write(bytearray(data))

    def i2c_writebyte(self, reg, value):
        wbuf = [(reg>>8)&0xff, reg&0xff, value]
        self.i2c.writeto(self.address, bytearray(wbuf))

    def i2c_write(self, reg):
        wbuf = [(reg>>8)&0xff, reg&0xff]
        self.i2c.writeto(self.address, bytearray(wbuf))

    def i2c_readbyte(self, reg, len):
        self.i2c_write(reg)
        rbuf = bytearray(len)
        self.i2c.readfrom_into(self.address, rbuf)
        return rbuf

    def module_exit(self):
        self.digital_write(self.reset_pin, 0)
        self.digital_write(self.trst_pin, 0)


class EPD_2in9:
    def __init__(self):
        self.config = config(0x48)

        self.width = EPD_WIDTH
        self.height = EPD_HEIGHT

        self.black = 0x00
        self.white = 0xff
        self.darkgray = 0xaa
        self.grayish = 0x55
        
        self.lut = WF_PARTIAL_2IN9
        self.lut_l = WF_PARTIAL_2IN9_Wait

        self.buffer_4Gray = bytearray(self.height * self.width // 4)
        self.image4Gray = framebuf.FrameBuffer(self.buffer_4Gray, self.width, self.height, framebuf.GS2_HMSB)
        self.buffer = bytearray(self.height * self.width // 8)
        self.image1Gray_Portrait = framebuf.FrameBuffer(self.buffer, self.width, self.height, framebuf.MONO_HLSB)
        

    # Hardware reset
    def reset(self):
        self.config.digital_write(self.config.reset_pin, 1)
        self.config.delay_ms(50) 
        self.config.digital_write(self.config.reset_pin, 0)
        self.config.delay_ms(2)
        self.config.digital_write(self.config.reset_pin, 1)
        self.config.delay_ms(50)   

    def send_command(self, command):
        self.config.digital_write(self.config.dc_pin, 0)
        self.config.digital_write(self.config.cs_pin, 0)
        self.config.spi_writebyte([command])
        self.config.digital_write(self.config.cs_pin, 1)

    def send_data(self, data):
        self.config.digital_write(self.config.dc_pin, 1)
        self.config.digital_write(self.config.cs_pin, 0)
        self.config.spi_writebyte([data])
        self.config.digital_write(self.config.cs_pin, 1)
        
    def ReadBusy(self):
        # print("e-Paper busy")
        while(self.config.digital_read(self.config.busy_pin) == 1):      #  0: idle, 1: busy
            self.config.delay_ms(10) 
        # print("e-Paper busy release")  

    def TurnOnDisplay(self):
        self.send_command(0x22) # DISPLAY_UPDATE_CONTROL_2
        self.send_data(0xF7)
        self.send_command(0x20) # MASTER_ACTIVATION
        self.ReadBusy()

    def TurnOnDisplay_Partial(self):
        self.send_command(0x22) # DISPLAY_UPDATE_CONTROL_2
        self.send_data(0x0F)
        self.send_command(0x20) # MASTER_ACTIVATION
        self.ReadBusy()

    def TurnOnDisplay_4Gray(self):
        self.send_command(0x22) # DISPLAY_UPDATE_CONTROL_2
        self.send_data(0xC7)
        self.send_command(0x20) # MASTER_ACTIVATION
        self.ReadBusy()

    def delay_ms(self, delaytime):
        utime.sleep(delaytime / 1000.0)

    def SendLut(self, isQuick):
        self.send_command(0x32)
        if(isQuick):
            lut = self.lut    
        else:
            lut = self.lut_l

        for i in range(0, 153):
            self.send_data(lut[i])
        self.ReadBusy()

    def SetWindow(self, x_start, y_start, x_end, y_end):
        self.send_command(0x44) # SET_RAM_X_ADDRESS_START_END_POSITION
        # x point must be the multiple of 8 or the last 3 bits will be ignored
        self.send_data((x_start>>3) & 0xFF)
        self.send_data((x_end>>3) & 0xFF)
        self.send_command(0x45) # SET_RAM_Y_ADDRESS_START_END_END_POSITION
        self.send_data(y_start & 0xFF)
        self.send_data((y_start >> 8) & 0xFF)
        self.send_data(y_end & 0xFF)
        self.send_data((y_end >> 8) & 0xFF)

    def SetCursor(self, x, y):
        self.send_command(0x4E) # SET_RAM_X_ADDRESS_COUNTER
        # x point must be the multiple of 8 or the last 3 bits will be ignored
        self.send_data((x>>3) & 0xFF)
        
        self.send_command(0x4F) # SET_RAM_Y_ADDRESS_COUNTER
        self.send_data(y & 0xFF)
        self.send_data((y >> 8) & 0xFF)
        self.ReadBusy()

    def SetLut(self, lut):
        self.send_command(0x32)
        for i in range(0, 153):
            self.send_data(lut[i])
        self.ReadBusy()
        self.send_command(0x3f)
        self.send_data(lut[153])
        self.send_command(0x03);	# gate voltage
        self.send_data(lut[154])
        self.send_command(0x04);	# source voltage
        self.send_data(lut[155])	# VSH
        self.send_data(lut[156])	# VSH2
        self.send_data(lut[157])	# VSL
        self.send_command(0x2c);		# VCOM
        self.send_data(lut[158])

    def init(self):
        # EPD hardware init start     
        self.reset()

        self.ReadBusy()   
        self.send_command(0x12)  #SWRESET
        self.ReadBusy()   

        self.send_command(0x01) #Driver output control      
        self.send_data(0x27)
        self.send_data(0x01)
        self.send_data(0x00)
    
        self.send_command(0x11) #data entry mode       
        self.send_data(0x03)

        self.SetWindow(0, 0, self.width-1, self.height-1)

        self.send_command(0x21) #  Display update control
        self.send_data(0x00)
        self.send_data(0x80)	
    
        self.SetCursor(0, 0)
        self.ReadBusy()
        # EPD hardware init end
        return 0
    
    def init_4Gray(self):
        self.reset()

        self.ReadBusy()
        self.send_command(0x12)  #SWRESET
        self.ReadBusy() 

        self.send_command(0x01) #Driver output control      
        self.send_data(0x27)
        self.send_data(0x01)
        self.send_data(0x00)
    
        self.send_command(0x11) #data entry mode       
        self.send_data(0x03)
        
        self.SetWindow(8, 0, self.width, self.height-1)

        self.send_command(0x3C)
        self.send_data(0x04)
    
        self.SetCursor(8, 0)
        self.ReadBusy()

        self.SetLut(Gray4)
        # EPD hardware init end
        return 0

    def display(self, image):
        if (image == None):
            return            
        self.send_command(0x24) # WRITE_RAM
        for i in range(0, self.height * int(self.width/8)):
            # for i in range(0, int(self.width / 8)):
            self.send_data(image[i])   
        self.TurnOnDisplay()

    def display_Base(self, image):
        if (image == None):
            return   
        self.send_command(0x24) # WRITE_RAM
        for i in range(0, self.height * int(self.width/8)):
            self.send_data(image[i])
        self.send_command(0x26) # WRITE_RAM
        for i in range(0, self.height * int(self.width/8)):
            self.send_data(image[i])
        self.TurnOnDisplay()
        
    def display_Partial(self, image):
        if (image == None):
            return
            
        self.config.digital_write(self.config.reset_pin, 0)
        self.config.delay_ms(0.2)
        self.config.digital_write(self.config.reset_pin, 1) 
        
        self.SendLut(1)
        self.send_command(0x37)
        self.send_data(0x00)
        self.send_data(0x00)  
        self.send_data(0x00)  
        self.send_data(0x00) 
        self.send_data(0x00)  	
        self.send_data(0x40)  
        self.send_data(0x00)  
        self.send_data(0x00)   
        self.send_data(0x00)  
        self.send_data(0x00)

        self.send_command(0x3C) #BorderWavefrom
        self.send_data(0x80)

        self.send_command(0x22) 
        self.send_data(0xC0)   
        self.send_command(0x20) 
        self.ReadBusy()

        self.SetWindow(0, 0, self.width - 1, self.height - 1)
        self.SetCursor(0, 0)
        
        self.send_command(0x24) # WRITE_RAM
        for i in range(0, self.height * int(self.width/8)):
            self.send_data(image[i])
        self.TurnOnDisplay_Partial()


    def display_4Gray(self, image):
        self.send_command(0x24)
        for i in range(0, 4736):
            temp3=0
            for j in range(0, 2):
                temp1 = image[i*2+j]
                for k in range(0, 2):
                    temp2 = temp1&0x03 
                    if(temp2 == 0x03):
                        temp3 |= 0x00   # white
                    elif(temp2 == 0x00):
                        temp3 |= 0x01   # black
                    elif(temp2 == 0x02):
                        temp3 |= 0x00   # gray1
                    else:   # 0x01
                        temp3 |= 0x01   # gray2
                    temp3 <<= 1

                    temp1 >>= 2
                    temp2 = temp1&0x03 
                    if(temp2 == 0x03):   # white
                        temp3 |= 0x00
                    elif(temp2 == 0x00):   # black
                        temp3 |= 0x01
                    elif(temp2 == 0x02):
                        temp3 |= 0x00   # gray1
                    else:   # 0x01
                        temp3 |= 0x01   # gray2
                    
                    if (( j!=1 ) | ( k!=1 )):
                        temp3 <<= 1
                    temp1 >>= 2
            self.send_data(temp3)
            
        self.send_command(0x26)	       
        for i in range(0, 4736):
            temp3=0
            for j in range(0, 2):
                temp1 = image[i*2+j]
                for k in range(0, 2):
                    temp2 = temp1&0x03 
                    if(temp2 == 0x03):
                        temp3 |= 0x00   # white
                    elif(temp2 == 0x00):
                        temp3 |= 0x01   # black
                    elif(temp2 == 0x02):
                        temp3 |= 0x01   # gray1
                    else:   # 0x01
                        temp3 |= 0x00   # gray2
                    temp3 <<= 1

                    temp1 >>= 2
                    temp2 = temp1&0x03
                    if(temp2 == 0x03):   # white
                        temp3 |= 0x00
                    elif(temp2 == 0x00):   # black
                        temp3 |= 0x01
                    elif(temp2 == 0x02):
                        temp3 |= 0x01   # gray1
                    else:   # 0x01
                        temp3 |= 0x00   # gray2  
                    if(j!=1 or k!=1):                    
                        temp3 <<= 1
                    temp1 >>= 2
            self.send_data(temp3)

        self.TurnOnDisplay_4Gray()

    def Clear(self, color):
        self.send_command(0x24) # WRITE_RAM
        for i in range(0, self.height * int(self.width/8)):
            self.send_data(color)
        self.TurnOnDisplay()

    def sleep(self):
        self.send_command(0x10) # DEEP_SLEEP_MODE
        self.send_data(0x01)
        
        self.config.delay_ms(2000)
        self.module_exit()


class ICNT_Development():
    def __init__(self):
        self.Touch = 0
        self.TouchGestureid = 0
        self.TouchCount = 0
        
        self.TouchEvenid = [0, 1, 2, 3, 4]
        self.X = [0, 1, 2, 3, 4]
        self.Y = [0, 1, 2, 3, 4]
        self.P = [0, 1, 2, 3, 4]
    

# …（前面的程式碼保持不變）…

class ICNT86():
    def __init__(self):
        self.config = config(0x48)
    
    def ICNT_Reset(self):
        self.config.digital_write(self.config.trst_pin, 1)
        self.config.delay_ms(100)
        self.config.digital_write(self.config.trst_pin, 0)
        self.config.delay_ms(100)
        self.config.digital_write(self.config.trst_pin, 1)
        self.config.delay_ms(100)

    def ICNT_Write(self, Reg, Data):
        self.config.i2c_writebyte(Reg, Data)

    def ICNT_Read(self, Reg, len):
        return self.config.i2c_readbyte(Reg, len)
        
    def ICNT_ReadVersion(self):
        buf = self.ICNT_Read(0x000a, 4)
        print(buf)

    def ICNT_Init(self):
        self.ICNT_Reset()
        self.ICNT_ReadVersion()

    def ICNT_Scan(self, ICNT_Dev, ICNT_Old):
        buf = []
        mask = 0x00
        
        if(ICNT_Dev.Touch == 1):
            ICNT_Dev.Touch = 0
            buf = self.ICNT_Read(0x1001, 1)
            
            if(buf[0] == 0x00):
                self.ICNT_Write(0x1001, mask)
                self.config.delay_ms(1)
                return
            else:
                ICNT_Dev.TouchCount = buf[0]
                
                if(ICNT_Dev.TouchCount > 5 or ICNT_Dev.TouchCount < 1):
                    self.ICNT_Write(0x1001, mask)
                    ICNT_Dev.TouchCount = 0
                    return
                    
                buf = self.ICNT_Read(0x1002, ICNT_Dev.TouchCount*7)
                self.ICNT_Write(0x1001, mask)
                                
                ICNT_Old.X[0] = ICNT_Dev.X[0]
                ICNT_Old.Y[0] = ICNT_Dev.Y[0]
                ICNT_Old.P[0] = ICNT_Dev.P[0]
                
                for i in range(0, ICNT_Dev.TouchCount, 1):
                    ICNT_Dev.TouchEvenid[i] = buf[6 + 7*i] 
                    ICNT_Dev.X[i] = 127 - ((buf[4 + 7*i] << 8) + buf[3 + 7*i])
                    ICNT_Dev.Y[i] = ((buf[2 + 7*i] << 8) + buf[1 + 7*i])
                    ICNT_Dev.P[i] = buf[5 + 7*i]
                # print(ICNT_Dev.Y[0], ICNT_Dev.X[0], ICNT_Dev.P[0])
                return(296 - ICNT_Dev.Y[0], ICNT_Dev.X[0])
        return
    
def get_touch_coordinates(tp, icnt_dev, icnt_old):
    """
    檢查觸控中斷並執行觸控掃描，回傳第一個觸碰點的 (x, y) 座標
    若未偵測到觸碰則回傳 None
    """
    # 檢查中斷腳位：低電位表示有觸控
    if tp.config.digital_read(tp.config.int_pin) == 0:
        icnt_dev.Touch = 1
    else:
        icnt_dev.Touch = 0

    # 呼叫原有的觸控掃描函式
    data = tp.ICNT_Scan(icnt_dev, icnt_old)

    # 若偵測到觸控點則回傳第一個觸控點的座標
    if data:
        # print(data)
        return data
    else:
        return None

prev_touch = None
def get_touch_state(tp, icnt_dev, icnt_old):
    """
    偵測觸控向量，回傳 (delta_x, delta_y)。
    每次呼叫會比較前一次觸控點與目前的觸控點，若未偵測到觸碰則回傳 None。
    首次偵測時回傳 (0, 0)。
    """
    global prev_touch
    new_touch = (get_touch_coordinates(tp, icnt_dev, icnt_old), utime.ticks_ms())
    
    if new_touch[0] is None :
        return None
        
    if prev_touch is None:
        prev_touch = new_touch
        return ("Touch", new_touch[0])
    
    # 計算滑動向量
    state = "Drag"
    result = [new_touch[0][0] - prev_touch[0][0], new_touch[0][1] - prev_touch[0][1]]
        
    if abs(result[0]) < 5:
        result[0] = 0
    if abs(result[1]) < 5:
        result[1] = 0
        
    if abs(result[0]) + abs(result[1]) == 0 or new_touch[1] - prev_touch[1] > 200:
        state = "Touch"
        result = new_touch[0]

    # 更新前一次觸控點
    prev_touch = new_touch
        
    return (state, result)


# 將原本的示範/測試程式碼包裝於 __main__ 區塊中
if __name__ == "__main__":
    # 初始化觸控相關物件
    tp = ICNT86()
    icnt_dev = ICNT_Development()
    icnt_old = ICNT_Development()
    
    last_time = -1
    
    # 執行觸控模組初始化（根據原有程式碼）
    tp.ICNT_Init()
    
    while True:
        # 使用範例：
        state = get_touch_state(tp, icnt_dev, icnt_old)
        
        if state is not None:
            print("觸控狀態：", state)
            

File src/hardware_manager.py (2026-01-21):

# hardware_manager.py
import time
import dht
from machine import ADC, Pin
from epaper import ICNT86, ICNT_Development, get_touch_state

class HardwareManager:
    """Manages hardware components like ADC, buttons, and touch panel."""
    def __init__(self):
        """Initializes hardware components."""
        self.adc = ADC(Pin(26))

        self.button_1 = Pin(2, Pin.IN, Pin.PULL_UP)
        self.button_2 = Pin(3, Pin.IN, Pin.PULL_UP)
        self.button_3 = Pin(15, Pin.IN, Pin.PULL_UP)

        self.tp = ICNT86()
        self.icnt_dev = ICNT_Development()
        self.icnt_old = ICNT_Development()
        self.tp.ICNT_Init()
        
        # DHT22 temperature/humidity sensor on GP19
        self.dht_sensor = dht.DHT22(Pin(19))
        # Initialize to allow first read immediately (2001ms in the past)
        self.dht_last_read_ms = time.ticks_add(time.ticks_ms(), -2001)
        self.dht_last_temperature = None
        self.dht_last_humidity = None
        
        # Button long press detection
        self.button_press_timestamps = {}
        self.long_press_threshold_ms = 3000

    def get_adc_value(self):
        """Reads the ADC value from the light sensor."""
        return self.adc.read_u16()

    def get_button_states(self):
        """Reads the raw button states and inverts them."""
        raw_state_1 = self.button_1.value()
        raw_state_2 = self.button_2.value()
        raw_state_3 = self.button_3.value()

        inverted_state_1 = 1 if raw_state_1 == 0 else 0
        inverted_state_2 = 1 if raw_state_2 == 0 else 0
        inverted_state_3 = 1 if raw_state_3 == 0 else 0
        
        return (inverted_state_1, inverted_state_2, inverted_state_3)

    def get_touch_state(self):
        """Gets the current touch state from the touch panel."""
        return get_touch_state(self.tp, self.icnt_dev, self.icnt_old)
    
    def handle_button_long_press(self, callback=None):
        """Handle button long press detection with callback support.
        
        Args:
            callback: Function to call when long press is detected. 
                     Receives button index (0-2) as parameter.
                     
        Returns:
            True if long press was detected, False otherwise.
        """
        button_states = self.get_button_states()
        current_time_ms = time.ticks_ms()
        
        for i, state in enumerate(button_states):
            if state == 1:  # Button is pressed
                if i not in self.button_press_timestamps:
                    # Record the start of button press
                    self.button_press_timestamps[i] = current_time_ms
                else:
                    # Check if long press threshold is reached
                    press_duration = time.ticks_diff(current_time_ms, self.button_press_timestamps[i])
                    
                    if press_duration >= self.long_press_threshold_ms:
                        print(f"Button {i+1} long pressed for {press_duration} ms")
                        
                        # Call the callback if provided
                        if callback:
                            callback(i)
                            
                        # Clear the timestamp to prevent repeated calls
                        del self.button_press_timestamps[i]
                        return True
            else:
                # Button is released, clear timestamp
                if i in self.button_press_timestamps:
                    del self.button_press_timestamps[i]
        
        return False
    
    def get_temperature_humidity(self):
        """Reads temperature and humidity from DHT22 sensor with built-in throttling.
        
        Returns:
            tuple: (temperature_celsius, humidity_percent) on success, None on failure.
                   Returns cached values if called within 2 seconds of last read.
        """
        current_time_ms = time.ticks_ms()
        
        # Throttling: DHT22 requires minimum 2 seconds between reads
        if time.ticks_diff(current_time_ms, self.dht_last_read_ms) < 2000:
            # Return cached values if available
            if self.dht_last_temperature is not None and self.dht_last_humidity is not None:
                return (self.dht_last_temperature, self.dht_last_humidity)
            return None
        
        try:
            # Read sensor (measure() must be called before reading values)
            self.dht_sensor.measure()
            temperature = self.dht_sensor.temperature()
            humidity = self.dht_sensor.humidity()
            
            # Update throttle timestamp regardless of value validity
            self.dht_last_read_ms = current_time_ms
            
            # Validate sensor values before caching
            if temperature is not None and humidity is not None:
                # Cache successful read
                self.dht_last_temperature = temperature
                self.dht_last_humidity = humidity
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

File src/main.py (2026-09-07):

# main.py
import time
import gc
from wifi_manager import wifi_manager, create_lan_config_server
from netutils import sync_time, get_local_time
from discord_notifier import send_lan_ip, consume_autoreset_ip


# Keep the first TLS allocation ahead of the display, sensor, weather, and
# controller imports.  Those modules are intentionally loaded below only
# after the startup webhook has had its low-memory window.
_startup_wlan = wifi_manager()
_startup_lan_ip = None
_startup_network_connected = bool(_startup_wlan and _startup_wlan.isconnected())
_startup_discord_sent = False
# Consumed before the connected check, not inside it: the note describes *this*
# boot, and one that comes up without a link has no notice to suppress.  Leaving
# it behind would apply it to some later boot that has every reason to announce.
_autoreset_ip = consume_autoreset_ip()
if _startup_network_connected:
    _startup_lan_ip = _startup_wlan.ifconfig()[0]
    _startup_wlan = None
    gc.collect()
    sync_time()
    # A memory auto-reset buys exactly one usable TLS window, and the online
    # notice would spend it repeating an address the user was already told.
    # Skip it in that case and let the pending backlog below have the window --
    # the whole point of the reboot.  The note is consumed on read, so a power
    # cycle or a changed address still announces normally.
    #
    # "Unchanged" means the same IPv4 string, deliberately: a different network
    # that hands out the same address would also be skipped, but the announced
    # URL still works there, and the note only ever survives from an auto-reset
    # to the boot it caused -- moving the device involves a power cycle, which
    # clears it.
    if _startup_lan_ip and _autoreset_ip == _startup_lan_ip:
        print("Info: LAN IP unchanged after a memory auto-reset; skipping the online notice.")
        # Marked sent so the controller does not retry it every 30 s either.
        _startup_discord_sent = True
    else:
        _startup_discord_sent = send_lan_ip(_startup_lan_ip) is True
    from discord_notifier import send_presence_session, send_presence_summary
    from presence_manager import PresenceManager

    startup_presence = PresenceManager(
        discord_sender=send_presence_summary,
        session_sender=send_presence_session
    )
    flushed = startup_presence.flush_startup_discord()
    if flushed:
        print("Info: Flushed {} pending Discord notification(s) before app init.".format(flushed))
    startup_presence = None
    gc.collect()
_startup_wlan = None


# Fetch weather while only the low-dependency startup modules are resident.
# Loading the display, sensor, image catalog and controller first fragments the
# heap enough for the Pico W TLS allocation to fail even when mem_free is large.
_startup_weather_current = None
_startup_weather_forecast = None
_startup_weather_timezone = 8
if _startup_network_connected:
    try:
        from config_manager import config_manager
        from weather import fetch_current_weather, fetch_weather_forecast

        _startup_weather_latitude = config_manager.get("weather.latitude")
        _startup_weather_longitude = config_manager.get("weather.longitude")
        _startup_weather_timezone = config_manager.get("user.timezone_offset", 8)
        _startup_weather_current = fetch_current_weather(
            _startup_weather_latitude,
            _startup_weather_longitude,
            _startup_weather_timezone,
        )
        _startup_weather_forecast = fetch_weather_forecast(
            _startup_weather_latitude,
            _startup_weather_longitude,
            days_limit=5,
            timezone_offset=_startup_weather_timezone,
        )
    except Exception as e:
        print("Warning: Startup weather prefetch failed. Details: {}".format(e))
    finally:
        gc.collect()


def main():
    """Main function to initialize and run the Pico Clock Weather Display application."""
    from display_manager import update_page_loading
    from app_state import AppState
    from hardware_manager import HardwareManager
    from app_controller import AppController
    from image_manager import image_store

    recovered = image_store.recover_partial_uploads()

    if recovered:
        print("Recovered {} interrupted image transaction(s).".format(recovered))

    # Initial display and hardware setup follows the memory-sensitive webhook.
    update_page_loading(False)
    app_state = AppState()
    startup_weather_ms = time.ticks_ms()
    startup_weather_prefetched = bool(_startup_weather_current or _startup_weather_forecast)
    if startup_weather_prefetched:
        # _handle_date_change() treats last_day == -1 as a new day and clears
        # all weather state.  Seed it here so a successful low-memory startup
        # fetch is used by the first display pass instead of being fetched again
        # after the display modules have fragmented the heap.
        app_state.last_day = get_local_time(offset=_startup_weather_timezone * 3600)[2]
    if _startup_weather_current:
        app_state.current_weather = _startup_weather_current
        app_state.current_weather_last_updated = startup_weather_ms
        app_state.current_weather_last_attempted = startup_weather_ms
    if _startup_weather_forecast:
        app_state.weather_forecast = _startup_weather_forecast
        app_state.weather_forecast_last_updated = startup_weather_ms
        app_state.weather_forecast_last_attempted = startup_weather_ms
    hardware = HardwareManager()

    controller = AppController(app_state, hardware, None, _startup_lan_ip)
    controller.startup_discord_sent = _startup_discord_sent

    if _startup_network_connected:
        controller.lan_server = create_lan_config_server()

    while True:
        controller.run_main_loop()
        time.sleep(1)


if __name__ == "__main__":
    main()

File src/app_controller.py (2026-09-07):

# app_controller.py
import time
import gc
from config_manager import config_manager
from netutils import sync_time, get_local_time
from weather import fetch_current_weather, fetch_weather_forecast
from display_manager import update_page_weather, update_page_time_image, update_page_birthday, update_page_image_preview
from display_utils import clear_display_and_sleep, release_display_workspace
from image_manager import image_catalog, image_store
from wifi_manager import reset_wifi_and_reboot
from chime import Chime
from discord_notifier import send_lan_ip, send_presence_session, send_presence_summary
from presence_manager import PresenceManager, set_presence_manager
from env_manager import EnvManager, set_env_manager

STARTUP_DISCORD_DELAY_MS = 45 * 1000
STARTUP_DISCORD_RETRY_MS = 30 * 1000
# Heap fragmentation can push the TLS handshake permanently out of reach; only a
# reboot restores a contiguous heap.  Reboot as a last resort, with a cooldown so
# a genuinely unreachable webhook cannot turn into a boot loop.
#
# Measured on device 2026-07-26 (MicroPython 1.24.1, .mpy deployment): once the
# app reaches steady state the largest contiguous block is only ~10 KiB against a
# 20 KiB threshold, and release_display_workspace() does not move it at all.  So
# waiting does not help -- the reboot's low-memory startup window is the only one
# ever observed to succeed.  Retrying 30 times first only delayed every
# notification by half an hour without changing the outcome.  (Single device,
# single firmware, .mpy deployment: re-measure before assuming it elsewhere.)
#
# Since waiting buys nothing, the threshold is set by what a reboot *costs* right
# now rather than by how long the stall has lasted.  presence_manager queues the
# session summary on the leave transition, so nearly every pending notification is
# born while the user is away: the panel has already been cleared and put to sleep,
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

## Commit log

2025-07-14 feat: 新增檔案管理、Wi-Fi 設定與天氣功能整合
    - 實作 `file_manager.py`，用於圖片檔案的列出、隨機排序與選取
    - 新增 `netutils.py`，處理 Wi-Fi 連線與時間同步
    - 新增 `weather.py`，透過 OpenWeather API 取得目前天氣與預報資料
    - 建立 `wifi_manager.py`，提供網頁介面供使用者設定 Wi-Fi
    - 實作 `main.py` 作為主程式，整合所有模組功能
    - 新增 `image_to_bin.py`，將圖片轉換為 1-bit 二進位格式供螢幕顯示
    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
    [clock.SLDPRT, clock_v3.SLDPRT]
2025-07-16 feat: Implement chime function and refactor application architecture
    - **Chime Functionality**:
    - Added `chime.py` module for hourly/half-hourly chimes via passive buzzer (Pin 20).
    - Chime settings (enable/disable, pitch, volume) are configurable via `config.json` and the AP mode setup page.
    - **AP Mode Enhancements**:
    - Added chime-related options to the AP mode setup page.
    - Real-time display of light sensor ADC value on the setup page, updating every 3 seconds.
    - Introduced `/adc` API endpoint for asynchronous sensor data retrieval.
    - **Application Architecture Refactoring**:
    - Split `main.py` into smaller, more focused modules (`app_controller.py`, `app_state.py`, `hardware_m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
    [app_controller.py, app_state.py, chime.py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]
2025-07-17 feat: Enhance AP mode settings and improve configuration flow
    - Add "Test Chime" button to AP mode settings page for immediate chime testing.
    - Optimize configuration saving process:
    - Parse and save settings before sending the success page.
    - Display saved configuration details on the success page (sensitive data masked).
    - Increase restart delay to 5 seconds to ensure client receives success page.
    - Fix `KeyError: 'font-family'` in `wifi_manager.py` by escaping CSS curly braces in HTML template.
    - Remove unused `test_chime` function from `chime.py`.
    - Update `CHANGELOG.md` and `README.md` to reflect these changes.
    [chime.py, wifi_manager.py]
2025-07-17 feat: Implement button long-press for Wi-Fi reset and refactor display functions
    - Implement long-press detection in `app_controller.py` to trigger Wi-Fi reset and device reboot.
    - Refactor `update_display_Restart` function from `wifi_manager.py` to `display_manager.py` for better modularity.
    - Adjust `get_button_states` in `hardware_manager.py` to invert raw button values (1 for pressed, 0 for unpressed).
    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
    [app_controller.py, display_manager.py, hardware_manager.py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]
2025-07-17 fix: Enhance stability and error handling for network and file operations
    - Implement robust retry mechanism for weather API requests in `src/weather.py`.
    - Improve error handling for image loading in `src/display_utils.py` and `src/file_manager.py`.
    - Ensure NTP synchronization and weather requests are skipped when no internet connection is available.
    - Translate all print messages to English across `src/weather.py`, `src/netutils.py`, `src/wifi_manager.py`, `src/file_manager.py`, and `src/display_utils.py`.
    - Address `NoneType` object errors by ensuring safe closing of network responses and robust JSON parsing.
    - Reorder `_perform_chime` call in `src/app_controller.py` to occur before `_up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
    [app_controller.py, display_utils.py, file_manager.py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]
2025-07-17 feat: 提升系統穩定性並優化 AP 模式使用者體驗
    本次更新包含多項系統穩定性增強與功能優化：
    1. **提升穩定性**:
    * 強化網路操作，為天氣 API、NTP 時間同步和圖片載入增加更穩健的重試與錯誤處理機制。
    * 修復 `urequests` 可能返回 `None` 的問題，避免 `NoneType` 錯誤。
    * 統一所有 `print` 輸出為英文，方便日誌分析。
    2. **優化 AP 模式**:
    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
2025-07-17 feat(core): 新增時區設定並優化天氣模組記憶體
    - **新增功能**:
    - 引入 `timezone_offset` 參數，允許使用者透過 AP 模式或 `config.json` 設定本地時區，以確保時間和天氣預報的準確性。
    - **效能優化**:
    - 大幅重構 `weather.py`，特別是 `fetch_weather_forecast` 函數，透過分段處理 JSON 回應來顯著降低記憶體消耗，解決 `MemoryError` 問題。
    - 在網路請求中加入更全面的錯誤處理（`OSError`, `MemoryError`）和手動垃圾回收，提升系統穩定性。
    - **重構**:
    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
2025-07-19 chore: 更新 README 和 weather_icons 資源圖片
2025-07-19 (fix): login picture random pick error
    [display_manager.py]
2025-07-20 refactor(core): 全面優化記憶體管理與更新機制
    本次提交對核心功能進行了深度重構，旨在解決設備因記憶體不足（MemoryError）而崩潰的問題，並提升系統整體的運行效率與穩定性。
    主要變更如下：
    1. **天氣模組重構 (`weather.py`)**:
    - 採用分段（chunked）方式讀取和解析天氣預報的 JSON 回應，取代了過去一次性載入完整資料的做法。此舉大幅降低了峰值記憶體使用量，從根本上消除了 `MemoryError` 的主要來源。
    2. **積極的記憶體回收 (`weather.py`, `display_utils.py`)**:
    - 在所有記憶體密集型操作（如 API 回應處理、圖片與畫布繪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
2025-07-21 feat(refactor): 全面提升程式碼品質與可讀性
    本次提交進行了大規模的程式碼重構與品質提升，主要包含以下幾個方面：
    - **程式碼註解英文化與 Docstrings**：
    - 將所有 `.py` 檔案中的中文註解和 `print` 訊息統一為英文。
    - 為所有主要類別和函式添加了詳細的 Docstrings，遵循 PEP 257 規範，提升了程式碼的自文件化程度與可維護性。
    - **重構與邏輯優化**：
    - **`wifi_manager.py`**：簡化了 AP 模式下設定的儲存邏輯，直接使用 `ConfigManager` 進行操作，並將 Wi-Fi 連線超時從 10 分鐘縮短為 1 分鐘，改善了使用者體驗。
    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
2025-07-29 feat: Enhance AP mode security and stability
    - **AP Mode Security Enhancement**:
    - Increased the default password length for AP mode to 8 characters ('12345678') and updated it in both `config.json.example` and `config_manager.py` to improve initial setup security.
    - **AP Mode Stability Improvement**:
    - **Refactored Settings Storage Logic**: In `wifi_manager.py`, the previously fragmented parameter parsing and settings storage process has been refactored. Settings are now first stored in a `dict` and then written in a unified manner, improving code readability and maintainability.
    - **Added Error Handling Page**: If a user submits incomplete or incorrectly formatted form data on the A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
    [config_manager.py, wifi_manager.py]
2025-08-01 fix(display): Correct date formatting for weather forecast
    - **Bug Fix**: In `display_manager.py`, ensured the day of the month is formatted with a leading zero (e.g., '07' instead of '7') when comparing with the weather forecast data. This prevents an issue where the current day's weather might not be correctly displayed in the forecast list on single-digit days.
    - **Changelog**: Updated `CHANGELOG.md` to reflect this fix under version 1.5.1.
    [display_manager.py]
2025-08-13 refactor: Unify button handling and enhance AP mode stability
    - **Refactor: Unified Button & Reset Logic**
    - Centralized the long-press detection logic into `hardware_manager.py` to provide a consistent 3-second trigger for resets.
    - Created a new `reset_wifi_and_reboot()` function in `wifi_manager.py` to standardize the system reset process from any mode (normal or AP).
    - This removes redundant code and ensures that a long press always results in the same behavior.
    - **Feature: AP Mode Enhancements**
    - Implemented a dynamic timeout that extends automatically with user activity, preventing the device from rebooting during configuration.
    - Enabled the long-press button reset functi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
    [app_controller.py, config_manager.py, hardware_manager.py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]
2025-12-30 feat: 新增多設定檔管理、Wi-Fi 管理、硬體設計檔案與圖片轉換工具，並更新文件。
    [clock_v3.SLDPRT]
2025-12-30 (fix): 網頁按鈕互動修復、AP 模式記憶體優化
2025-12-30 Release v2.0.1: Security fixes, upload.py improvements, and changelog update
    [wifi_manager.py]
2025-12-31 docs: 更新 README 說明
2026-01-21 feat: integrate DHT22 sensor for local temperature and humidity display
    - Update display_manager.py: add DHT22 parameters to weather page
    - Reorganize weather page layout:
    * Display DHT22 local temp/humidity in upper right
    * Show network current weather in forecast slot 1
    * Show 3-day forecast in slots 2-4
    - Update app_controller.py: pass DHT22 data to display layer
    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
2026-07-24 refactor: rename Pi Paper Clock to Pico Paper Clock
    Removes the last traces of the old name from the docs, the device web UI pages,
    the desktop tooling and the Discord online notification.
    The device identifier returned by GET /api/v1/device also becomes
    pico-paper-clock. That value is a wire contract, so the desktop image tool
    accepts both spellings: a device still running pre-v2.6.0 firmware remains
    reachable from an updated tool.
2026-07-24 fix(discord): guard TLS sends against heap fragmentation
    Discord notifications stopped permanently after ~12 days of uptime and only a
    power cycle brought them back. The TLS handshake needs a ~18-23 KiB *contiguous*
    block, not just free bytes: on device, gc.mem_free() reported ~57 KB while the
    largest contiguous block was only ~17.9 KB. Measured on MicroPython 1.24.1,
    ssl.wrap_socket raises OSError ENOMEM at 17,920 B and succeeds at 23,120 B.
    release_display_workspace() buys back only ~5.2 KiB, and flush_discord() had no
    escape path -- it just retried the doomed handshake every 60 s forever.
    flush_discord() now establishes why a send is impossible before blaming memory:
    delivery_blocked() r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
    [app_controller.py, discord_notifier.py, presence_manager.py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]
2026-07-28 fix(discord): pick the auto-reset threshold by presence state
    Steady-state measurements (2026-07-26, MicroPython 1.24.1, .mpy) show the
    largest contiguous block sits at ~10 KiB against a 20 KiB TLS threshold, and
    release_display_workspace() does not move it. Waiting therefore buys nothing:
    the reboot's low-memory startup window is the only one ever observed to
    deliver. The threshold now reflects what a reboot costs at that moment instead
    of how long the stall has lasted.
    presence_manager queues the session summary on the leave transition, so nearly
    every pending notification is born while the panel is already cleared and
    asleep and nobody is watching -- two failures (~2 min) are enough ther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
    [app_controller.py, app_state.py, test_app_controller.py]
2026-07-28 feat(discord): skip the online notice when an auto-reset kept the same IP
    A memory auto-reset buys exactly one usable TLS window -- the low-memory
    startup phase before the display, sensor and controller modules load. Until
    now the first thing that window did was re-announce a LAN IP the user already
    knew, leaving the pending presence backlog to wait for the next reboot at least
    two hours later. The reboot exists to deliver that backlog.
    _check_discord_stall() now records the already-announced IP before rebooting,
    and the startup path skips the notice when the address comes back unchanged,
    marking it sent so the controller does not retry it every 30 s either.
    Three boundaries decide when th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
    [app_controller.py, discord_notifier.py, main.py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]
2026-09-07 fix: avoid blocking Wi-Fi scan during settings load
    [test_settings_ui.py]

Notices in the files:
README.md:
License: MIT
